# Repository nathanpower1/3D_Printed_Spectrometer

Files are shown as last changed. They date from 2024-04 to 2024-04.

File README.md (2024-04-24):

# 3D_Printed_Spectrometer
Final Report of my undergraduate Experimental Physics Career: The Development of a 3D Printed Handheld Miniature Visible Spectrometer

## Components

- **3D Printer Files**: Contains files necessary for 3D printing desgins.
- **3D Print Spectral Pics**: Spectral pictures produced through 3D printing technology.
- **MiscResultsFile**: Miscellaneous results files related to the project.
- **New Spectrometer Spectral Pics**: Spectral pictures obtained from new spectrometer design.
- **Old Spectrometer Final Data**: Final data obtained from the old spectrometer design.
- **Old Spectrometer Spectral Pics**: Spectral pictures obtained from the old spectrometer design.
- **Research Papers**: Papers used as research as part of this project.
- **Data Analysis.ipynb**: Jupyter Notebook containing data analysis scripts.
- **Physics Project Nathan Power.pptm**: Presentation slides for the project.
- **The Development of a 3D Printed Spectrometer**: Final writeup for the project. 

## Usage

1. Access the relevant folders to explore specific components of the project.
2. Utilize the 3D printer files to reproduce the spectrometer.
3. Review research papers for insights and background information on the project.

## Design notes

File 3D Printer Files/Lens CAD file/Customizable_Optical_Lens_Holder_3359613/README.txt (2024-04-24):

Customizable Optical Lens Holder by greygoo on Thingiverse: https://www.thingiverse.com/thing:3359613

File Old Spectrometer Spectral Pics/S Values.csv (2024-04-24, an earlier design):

Distance | Gray_Value
0 | 100.000
1 | 17.586
2 | 17.586
3 | 17.851
4 | 18.345
5 | 18.460
6 | 17.943
7 | 18.000
8 | 18.161
9 | 18.609
10 | 18.483
11 | 19.195
12 | 18.908
13 | 19.264
14 | 18.793
15 | 19.448
16 | 19.701
17 | 19.713
18 | 19.391
19 | 19.264
20 | 19.322
21 | 19.701
22 | 20.034
23 | 20.034
24 | 19.943
25 | 19.632
26 | 19.920
27 | 20.092
28 | 20.448
29 | 20.080
30 | 20.575
31 | 20.011
32 | 20.575
33 | 20.839
34 | 21.057
35 | 21.103
36 | 21.402
37 | 21.632
38 | 21.862
39 | 21.563
40 | 21.575
41 | 21.253
42 | 21.598
43 | 21.000
44 | 21.655
45 | 22.414
46 | 22.241
47 | 21.782
48 | 22.368
49 | 22.770
50 | 22.701
51 | 23.195
52 | 23.379
53 | 22.977
54 | 23.057
55 | 23.172
56 | 23.414
57 | 23.678
58 | 23.345
59 | 23.310
60 | 23.379
61 | 23.494
62 | 23.517
63 | 23.897
64 | 24.092
65 | 24.207
66 | 24.172
67 | 24.989
68 | 25.207
69 | 25.230
70 | 25.322
71 | 25.885
72 | 25.644
73 | 25.931
74 | 26.494
75 | 26.529
76 | 26.425
77 | 26.391
78 | 26.483
79 | 26.828
80 | 27.126
81 | 27.218
82 | 26.954
83 | 27.494
84 | 27.552
85 | 27.897
86 | 28.149
87 | 28.885
88 | 28.621
89 | 28.759
90 | 28.517
91 | 28.782
92 | 28.425
93 | 28.276
94 | 28.632
95 | 28.782
96 | 28.713
97 | 28.908
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

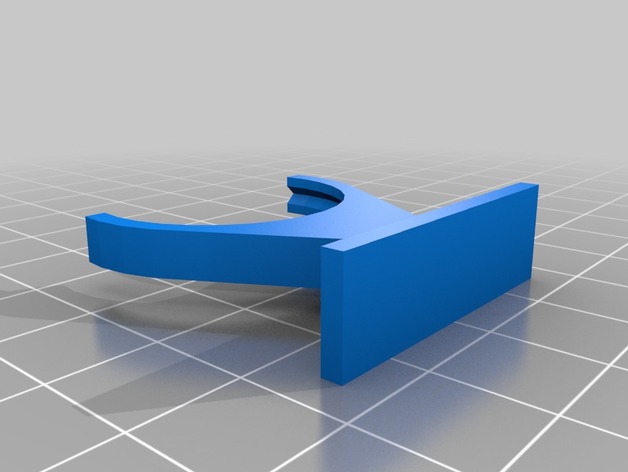
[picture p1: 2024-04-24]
3D Printer Files/Lens CAD file/Customizable_Optical_Lens_Holder_3359613/images/lense_holder_300x23.jpg

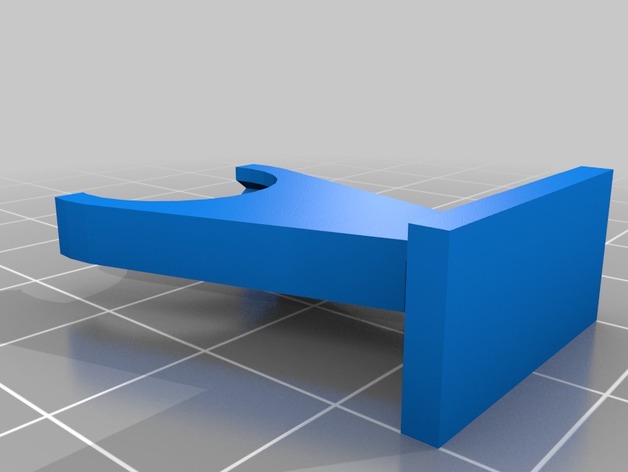
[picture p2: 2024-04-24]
3D Printer Files/Lens CAD file/Customizable_Optical_Lens_Holder_3359613/images/lense_holder_180x18.jpg

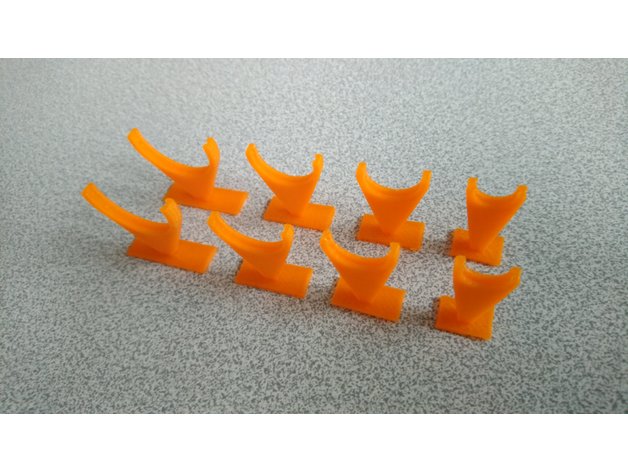
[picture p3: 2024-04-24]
3D Printer Files/Lens CAD file/Customizable_Optical_Lens_Holder_3359613/images/9351a503e8dcaec2e02d94f02c118ae2.jpg

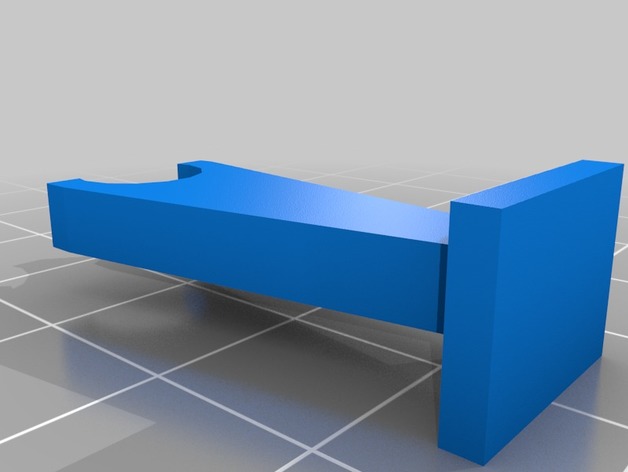
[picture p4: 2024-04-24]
3D Printer Files/Lens CAD file/Customizable_Optical_Lens_Holder_3359613/images/lense_holder_110x18.jpg

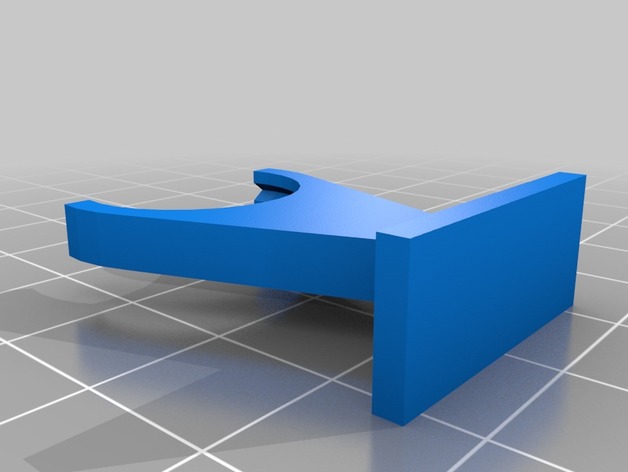
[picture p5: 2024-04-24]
3D Printer Files/Lens CAD file/Customizable_Optical_Lens_Holder_3359613/images/lense_holder_212x18.jpg

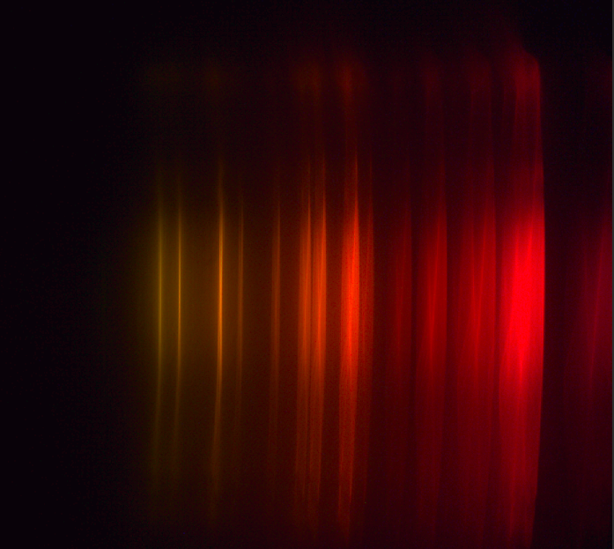
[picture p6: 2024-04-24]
New Spectrometer Spectral Pics/neon new spec 3.png

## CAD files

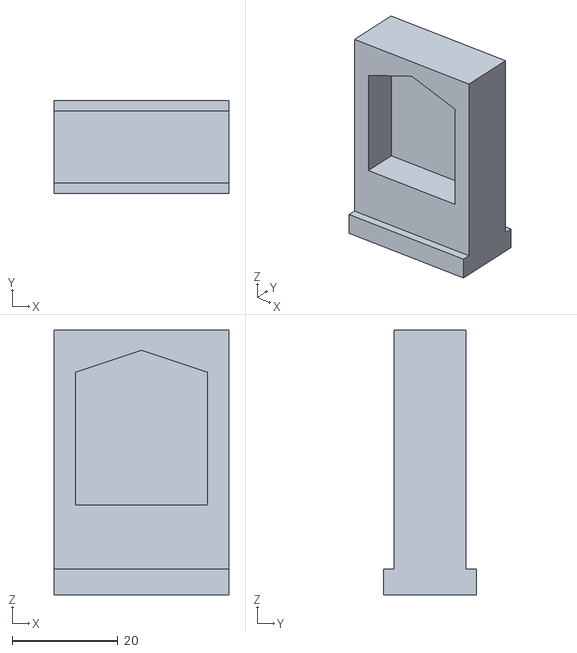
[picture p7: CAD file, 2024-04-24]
3D Printer Files/GratingFiles/New New Grating Holder v4.stl
33.0 x 17.5 x 50.0

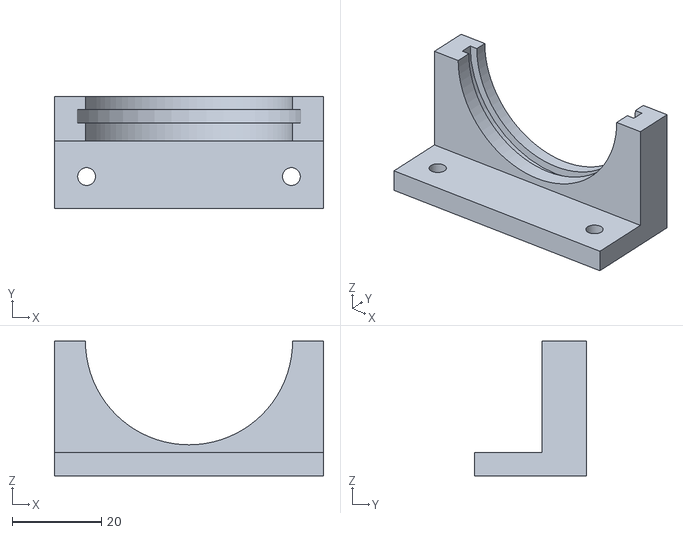
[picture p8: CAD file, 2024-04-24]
3D Printer Files/Lens CAD file/50mm-lens-holder20230105-61-r2lxff/jbeale/50mm-lens-holder/LensHolder.stl
60.4 x 25.2 x 30.2

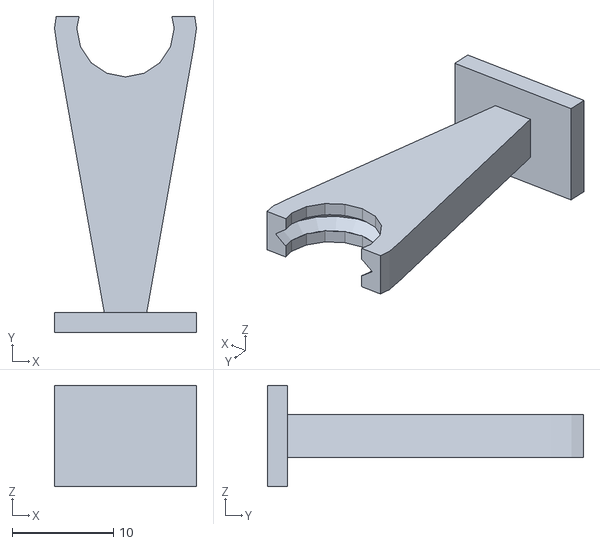
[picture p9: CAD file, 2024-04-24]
3D Printer Files/Lens CAD file/Customizable_Optical_Lens_Holder_3359613/files/lense_holder_120x18.stl
14.0 x 31.2 x 10.0

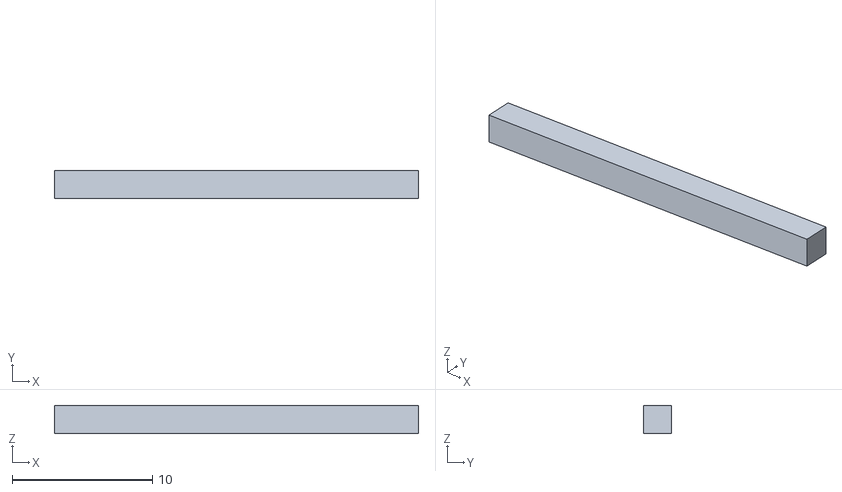
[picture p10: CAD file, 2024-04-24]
3D Printer Files/Lens CAD file/lens holder bar v1 Nathan Power.stl
26.0 x 2.00 x 2.00

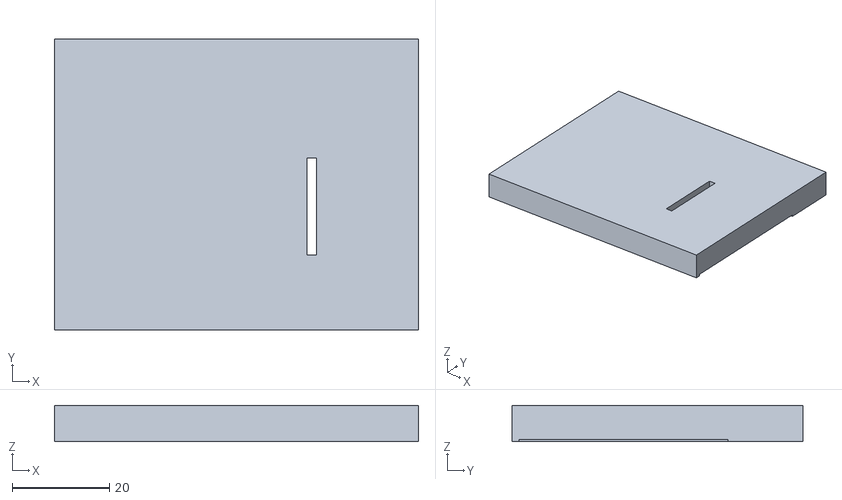
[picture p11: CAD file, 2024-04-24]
3D Printer Files/SlitFiles/Open Slit Face v2 Nathan Power.stl
75.0 x 60.0 x 7.50

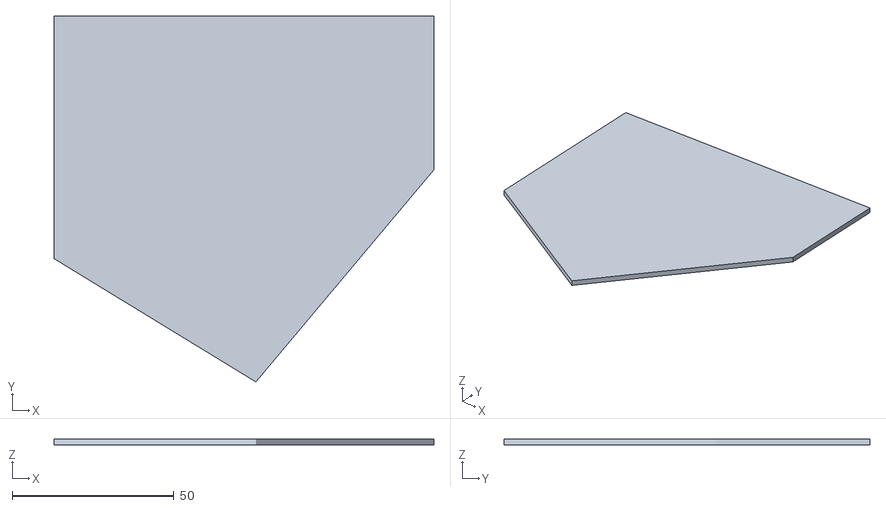
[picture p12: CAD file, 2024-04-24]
3D Printer Files/BaseFiles/Base v2.stl
117.5 x 113.1 x 2.00

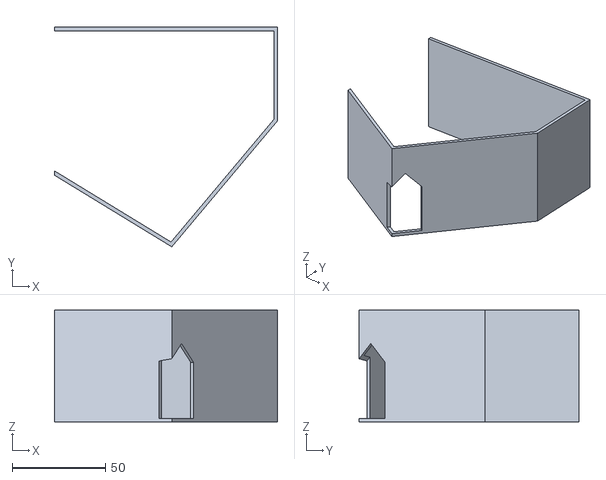
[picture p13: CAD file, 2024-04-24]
3D Printer Files/CamFiles/case 3 v5.stl
119.5 x 117.7 x 60.0

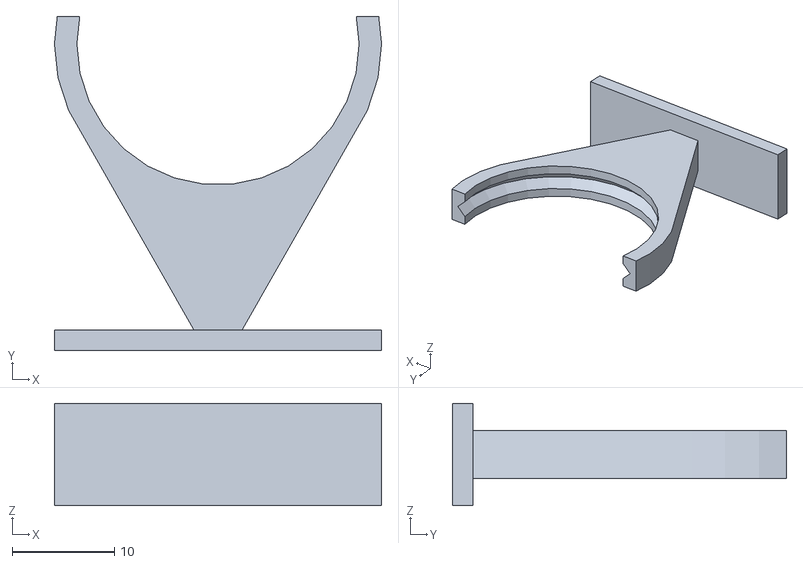
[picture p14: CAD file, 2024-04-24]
3D Printer Files/Lens CAD file/Customizable_Optical_Lens_Holder_3359613/files/lense_holder_300x23.stl
32.0 x 32.7 x 10.0

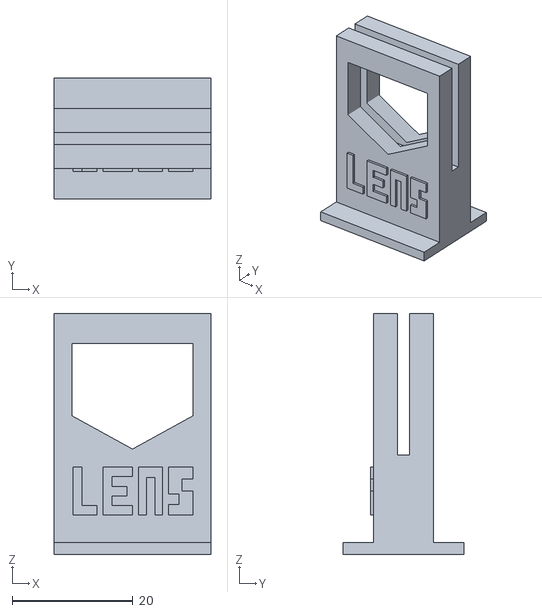
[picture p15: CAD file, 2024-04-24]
3D Printer Files/Lens CAD file/Lens Holder v3 Nathan Power.stl
26.0 x 20.0 x 40.0

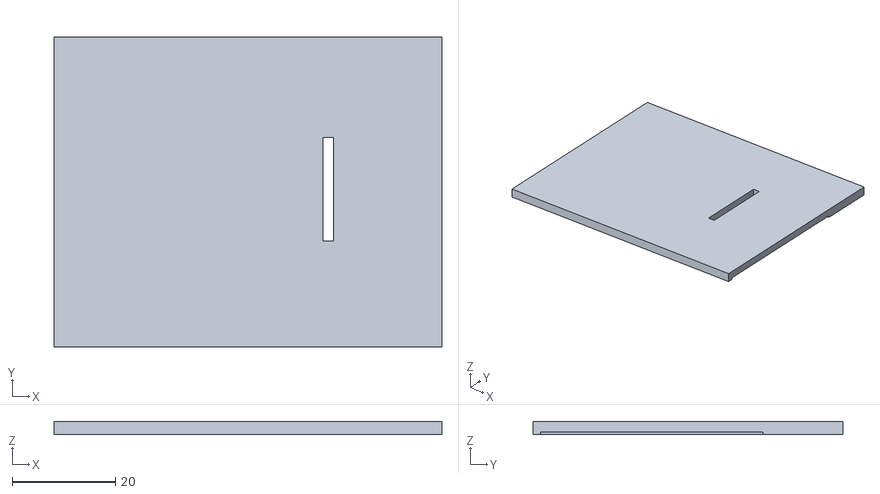
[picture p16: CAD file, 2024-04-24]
3D Printer Files/SlitFiles/Open Slit Face v4.stl
75.0 x 60.0 x 2.50

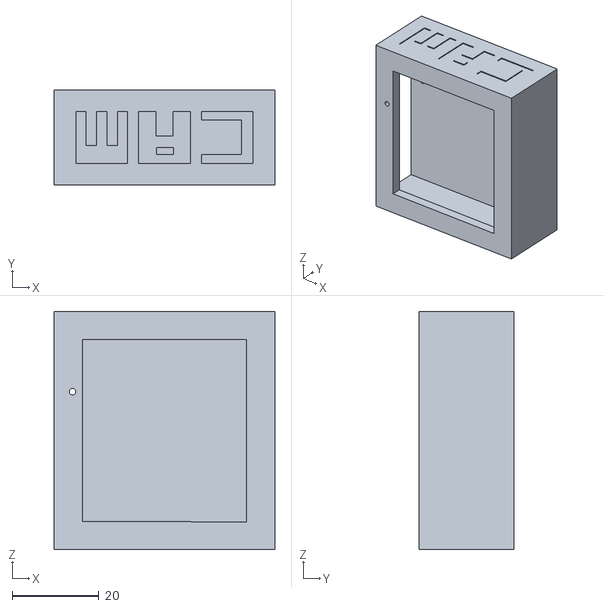
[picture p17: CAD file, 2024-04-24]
3D Printer Files/CamFiles/Camera Holder v5 Nathan Power.stl
51.0 x 22.0 x 55.0

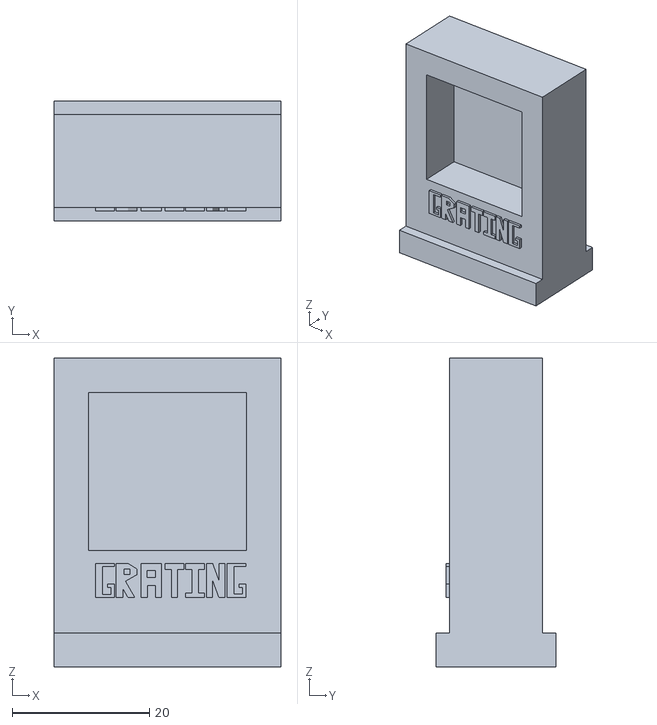
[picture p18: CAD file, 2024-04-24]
3D Printer Files/GratingFiles/Grating Holder v2 Nathan Power.stl
33.0 x 17.5 x 45.0

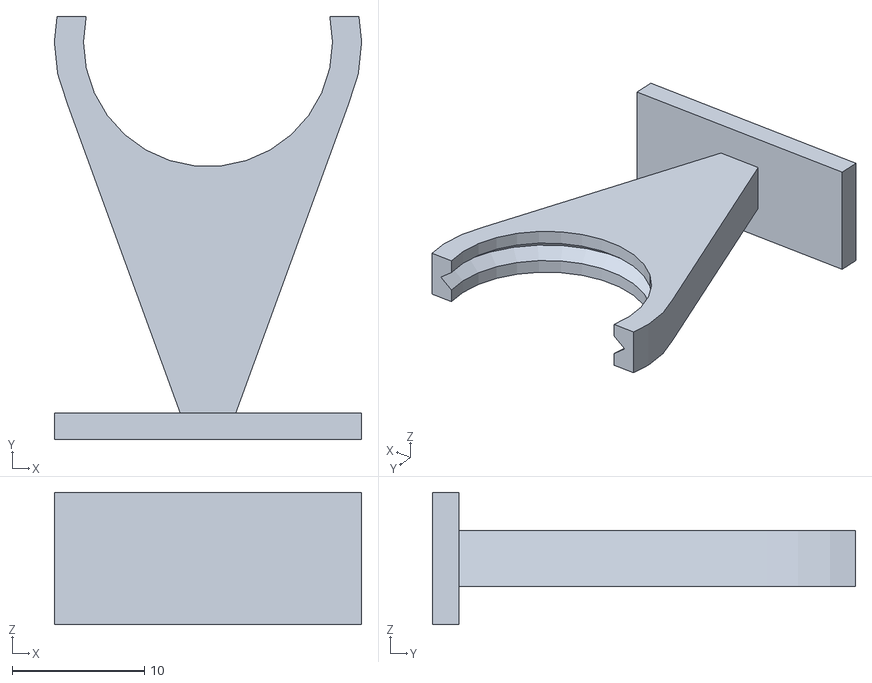
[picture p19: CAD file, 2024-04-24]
3D Printer Files/Lens CAD file/Customizable_Optical_Lens_Holder_3359613/files/lense_holder_212x18.stl
23.2 x 31.9 x 10.0

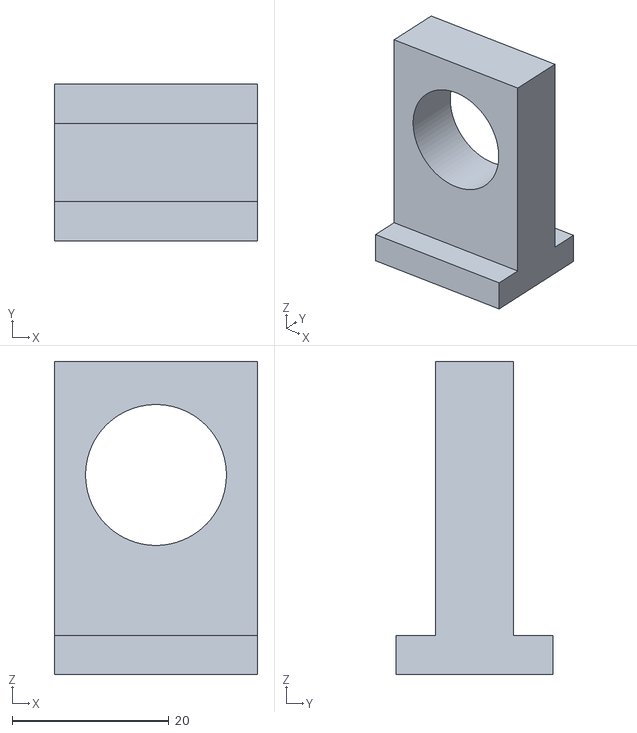
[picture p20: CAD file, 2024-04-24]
3D Printer Files/Lens CAD file/New New Lens Holder v1.stl
26.0 x 20.0 x 40.0

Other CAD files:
3D Printer Files/GratingFiles/New Grating Holder v3.stl
3D Printer Files/SlitFiles/FixedBlade.stl
3D Printer Files/CamFiles/Camera v2.stl
3D Printer Files/Lens CAD file/Customizable_Optical_Lens_Holder_3359613/files/lense_holder_110x18.stl
3D Printer Files/Lens CAD file/Customizable_Optical_Lens_Holder_3359613/files/lense_holder_customizable.scad
3D Printer Files/Lens CAD file/50mm-lens-holder20230105-61-r2lxff/jbeale/50mm-lens-holder/LensHolder.scad
3D Printer Files/BaseFiles/Base v1.f3d
3D Printer Files/BaseFiles/Base v1.stl
3D Printer Files/BaseFiles/Base v2.f3d
3D Printer Files/CamFiles/Case v1 Nathan Power.stl
3D Printer Files/CamFiles/Screw for CCD v1 Nathan Power.stl
3D Printer Files/Lens CAD file/Customizable_Optical_Lens_Holder_3359613/files/lense_holder_180x18.stl
3D Printer Files/Lens CAD file/New Lens Holder v1 Nathan Power.stl
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

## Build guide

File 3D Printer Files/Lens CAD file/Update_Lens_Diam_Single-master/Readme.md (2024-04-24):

# Update and Export variations of Lens Cap Holder for 3d printing

This is a Python script to interface with Fusion 360's API for updating the CAD model of the Lens Cap holder.
It will prompt the user to provide a minimum and a maximum lens diameter, and the width of the camera strap.
Then, the script will create versions of the lens cap holder in 1 mm increments between the minimum and the maximum diameter, for the strap width indicated by the user. It will save all the variations as STL files in a directory indicated by the user.

If you'd like to learn more about this, [I wrote an article about how the script works](https://www.makerluis.com/the-power-of-python-and-fusion-360-for-3d-printing/).

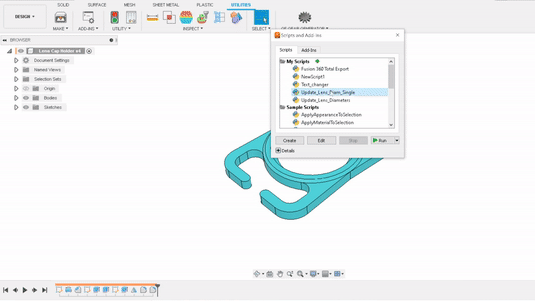
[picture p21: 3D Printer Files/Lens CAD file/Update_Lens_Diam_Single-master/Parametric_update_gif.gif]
Animated gif showing the automatic update of the model using a Python script Automatic update of the model using a Python script


#### [Download the STL files created with this parametric model](https://www.printables.com/model/129882-lens-cap-holder-for-camera-strap/comments) 
#### [Buy physical prints of the Lens Cap holder](https://vulkaza.com/collections/twothingies)

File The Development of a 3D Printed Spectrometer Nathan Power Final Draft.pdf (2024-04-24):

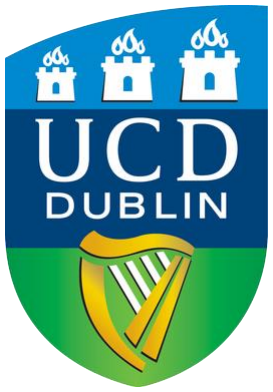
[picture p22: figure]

# The Development of a 3D-Printed Handheld Visible Spectrometer

# Nathan Power

## This project is submitted to University College Dublin in part fulfilment of the requirements for the degree:

# BSc (Hons) in Physics

### School of Physics

### Head of School: Professor Emma Sokell

### Supervisor: Assistant Professor Tom McCormack

### Submitted: April 26th, 2023

i | P a g e
i | The Development of a 3D-Printed Handheld Visible Spectrometer | Nathan Power

## Acknowledgements

I would like to thank my project supervisor, Assistant Professor Tom McCormack, for all his guidance, suggestions, and support during this project. Without his assistance, this project would not have been possible.

Collaboration with both the Electronics and Mechanics workshops in Science North was instrumental in this project, specifically, Robin O’Reilly and John Egan as they were very helpful during the 3D printing stage of this project. Thank you.

I would also like to thank Paul and Joe for their support and guidance in the labs not just during this project but also over the course of my undergraduate career.

Nathan Power

April 2023

## Abstract

This paper presents a design and implementation of a low-cost mini spectrometer that can be used for various applications in scientific research, education, and industry. The spectrometer was built using components already available in the lab and 3D printed housing and mounts, which reduced the cost significantly compared to commercially available spectrometers. The system is based on a flat diffraction grating and a CMOS sensor, and it covers the visible light spectrum from 460 to 620nm. The device is connected to a ThorLabs software for data analysis and visualization. The performance of the mini spectrometer was evaluated by measuring the spectra of different light sources and comparing them to the spectra obtained from literature. The results show that our mini spectrometer provides accurate and reliable spectral data with a resolution of approximately 2nm. The low-cost mini spectrometer presented in this paper can be a valuable tool for researchers, educators, and hobbyists who require spectral analysis but have limited budgets and/or space.

The Development of a 3D-Printed Handheld Visible Spectrometer | Nathan Power

## Table of Contents

Abstract | Error! Bookmark not defined.

The Development of a 3D-Printed Handheld Visible Spectrometer | Nathan Power

1 | P a g e
1 | The Development of a 3D-Printed Handheld Visible Spectrometer | Nathan Power
1 | Introduction

While sitting in an optics lecture in the autumn trimester of my final year, not long after I had chosen this project title as my final year physics project, the class was advised by Professor Dominic Zerulla to “Never build your own spectrometer, it is not worth the heartbreak”. With this echoing in my mind, I decided then it was time to install an AutoCad programme and get to work. I now recommend to the reader: Never build your own spectrometer unless you have a lot of patience and an optics professor to prove wrong.

1.1 Goals/Aims of this Project.
The main goal of this project was to develop a 3D printed spectrometer which is handheld, low-cost and compact in nature. This was aimed to be achieved in conjunction with maintaining a high resolution and wide operational wavelength with the intent of being able to compete with other micro-spectrometers being offered on the market today.

I believe that this is an incredibly relevant project mainly since many micro-spectrometers available on the market today are extremely expensive. From my research on low-cost non-commercially built micro-spectrometers, many fall short of the mark due to their limited spectral resolutions. This limits the amount of information that can be derived from absorption and/or emission lines. My aim is to improve on this and maintain a 1-2nm spectral resolution all in a handheld portable device.

I also believe there is an important educational application of this project. The pedagogical benefit of teaching the principles of modern spectroscopy by utilizing a simple spectrometer setup can be majorly beneficial. Optical spectroscopy is an indispensable topic in scientific education for undergraduate physics students. Using this inexpensive setup, the quantum principles of light’s interaction with matter can be explained by means of atom line emission and absorption in a classroom setting with minimal set up time. Being a final-year undergraduate experimental physics student, I believe that labs and practical experiments are just as important as the theory when it comes to fully understanding topics. Most experiments in the undergraduate physics course require highly expensive and complex instruments and equipment which highlights the importance of this low-cost project, which could be developed at home independently even, once again.

So, in this report I will introduce an optical setup that meets the criterion of high-resolution spectroscopy which remarkably remains around a factor of ten less expensive than other commercial spectrometers of similar specifications.

2 | P a g e
2 | The Development of a 3D-Printed Handheld Visible Spectrometer | Nathan Power

## 2 Spectroscopy

Our understanding of the universe comes from an expanded understanding of light as a wave across a much wider spectrum than what we can see. This in turn has led to a wave of modern technologies. Some aiming to utilize light’s wave properties to transmit information, such as audio and visual communications. While others aim to measure spectral components of physical phenomena such as mass of particles, and the chemical make-up of matter both terrestrial and extra-terrestrial.

[1]

Spectroscopy is a scientific measurement technique that investigates and quantifies the interaction of light with matter. These light-matter interactions at the molecularlevel,such as emission, absorption, fluorescence, and scattering, can be measured and analysed. These interactions are qualitatively and quantitatively analysed with light measuring instruments. The qualitative analysis is used to establish the identity of a sample while a quantitative analysis is performed to estimate the concentration of a substance. Every substance and element interact differently with light frequencies and the resulting patterns act like their own signatures or fingerprints making it possible to identify them.

[1]

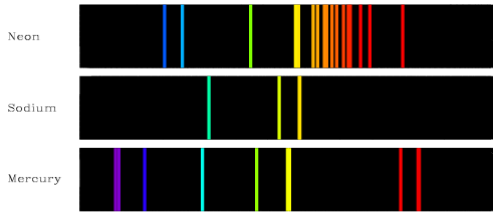
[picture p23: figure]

Fig 2.1: Emission Spectral Lines for Neon, Sodium and Mercury [2]

### 2.1 The Visible Light Spectrum

The reason that some things appear to be coloured at all to us is due to the fact that atoms and molecules absorb and emit different colours of light. So, a red shirt, for instance, appears red when sunlight shines on it because the shirt absorbs all the visible colours except the red light. Some of the red light passes through the shirt, and some is reflected from its surface. In this project, we are interested solely in the visible light spectrum.

The visible light spectrum is the segment of the electromagnetic spectrum that the human eye can view. This range of wavelengths, rather intuitively, is called visible light. Typically, the human eye can detect wavelengths from 380 to 700 nm. Cone-shaped cells in our eyes act as detectors tuned to the wavelengths in this narrow band of the spectrum. Other portions of the spectrum have wavelengths too large or too small and energetic for the biological limitations of our perception. [3] In
this report, we will explore the spectral lines of Neon, Sodium and Mercury which fall inside the visible spectrum of light.

3 | P a g e
3 | The Development of a 3D-Printed Handheld Visible Spectrometer | Nathan Power

## 3 The Spectrometer

### 3.1 What is a Spectrometer?

The spectrometer is now a common scientific instrument used to determine characteristic information about a sample by analysing its interactions with light and its spectral components. They enable us to study light’s wavelike properties to produce a spectrum and then measure the characteristics of the spectrum such as its wavelength, frequency and intensity. They can function over any range of the electromagnetic spectrum, but through their design and selection of appropriate optical components, as we will cover later, they typically operate in an application dependent region of the spectrum. [1]

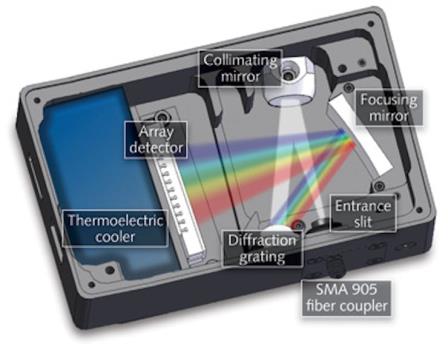
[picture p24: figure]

Fig 3.1: Typical Components of a Miniature Spectrometer [5]

### 3.2 How does a Spectrometer work?

So, what is a spectrometer and how does it work? The spectrometer as whole is a relatively simple device. The light from the sample first enters through the aptly named entrance slit and then is projected onto the collimating optic. The focal length of this optic is chosen so that it collimates the light emitted from the entrance slit and then directs the collimated beam of light onto the diffraction grating. After the light has been diffracted and separated into its chromatic components, the focusing or camera optic is used to focus the light dispersed from the grating onto the detector plane. In the case of a diffraction grating with given angular dispersion value, the focal length of the two mirrors/lenses can be designed to provide different linear dispersion values, which determines the spectral coverage for a given detector, resolution, and total length of the system. We will dive deeper into the workings of the spectrometer and its components later in this report.

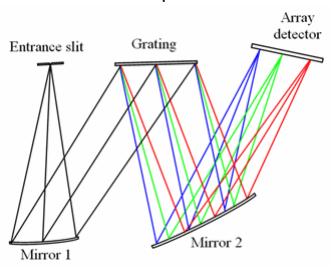
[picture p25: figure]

Fig 3.2: An Unfolded Czerny-Turner Spectrometer [1]

Perhaps the most common configuration for a spectrometer would be the Czerny-Turner configuration. A compact, flexible spectrograph design can be achieved by using the Czerny-Turner

4 | P a g e
4 | The Development of a 3D-Printed Handheld Visible Spectrometer | Nathan Power

making it an ideal setup for what we are aiming to achieve in this report. However, there are many other variations in which spectrometers can be assembled.

### 3.3 Applications of the Spectrometer

Spectrometers have a whole host of applications both in research and industrial settings. They are often used as analytical tools in R&D and manufacturing laboratories as well as in the field. Some applications include but are not limited to; determining concentrations of an element in food and beverages, identifying contaminants, checking for counterfeit or illegal substances, analysing biological compounds, performing medical analysis, and identifying structural defects.

Spectrometers can come in all shapes and sizes and with different specifications. It is possible to develop a spectrometer system which implements your smartphone within its setup. [6] Miniature spectrometers are a desirable commodity as they can be easily inserted within an experimental setup without having to sacrifice much space. The miniaturization of spectrometers has been taken to the extremes. For example, there has been a 3D-printed miniature spectrometer developed that is so small that it can fit on the tip of an endoscope or on a miniature image sensor with a footprint of 100 x 100 microns. [7]

## 4 Key Components of a Spectrometer

As previously mentioned in Section 3.2, there were five main important components to consider when building our spectrometer. These were the entrance slit, the collimating and focusing optics, the diffraction grating and the detector. The choice of these components was then bounded by the initial constraints chosen such as resolution and wavelength range which is what makes constructing spectrometers so incredibly tedious. This is why it wasso vital to have these ideal constraints and goals in mind when building our spectrometer, so it was then possible to choose the components carefully to achieve our goal.

### 4.1 The Entrance Slit

The slit is an opening that ultimately controls how much light enters the spectrometer. The width of the slit also controls the resolution. The narrower the slit is, the higher the resolution will become. However, narrower slits also decrease signal strength and throughput. These two factors are essential to balance when selecting a slit size. The angle of the light that enters the optical bench is also controlled by the slit.

Another function of the entrance slit (http://bwtek.com/spectrometer-part-1-the-slit/) is to define a clear-cut object for the spectrometer. One of the key factors that it impacts the throughput of the spectrograph is the height and width of this opening. The image width of the entrance slit is an important factor in finding the spectral resolution of the spectrometer when it is greater than the pixel width of the detector array. The image width of the entrance slit, Wi, can be estimated as: [8]

Wi = (M² × Ws

2 + W0

2
)

1
2

(1)

Where M is the magnification of the spectrometer that is set by the ratio of the focal length of the focusing optic to the collimating optic. Wo is the image broadening and Ws is the width of the entrance slit. The imaging broadening caused by the optical bench, Wo, is generally on the order of a few tens of µm for a Czerny-Turner configuration.

[8]

Therefore, reducing the width of the entrance slit below this value will not significantly improve the resolution of the system. The pixel width of the detector sets another limit on spectral resolution, as

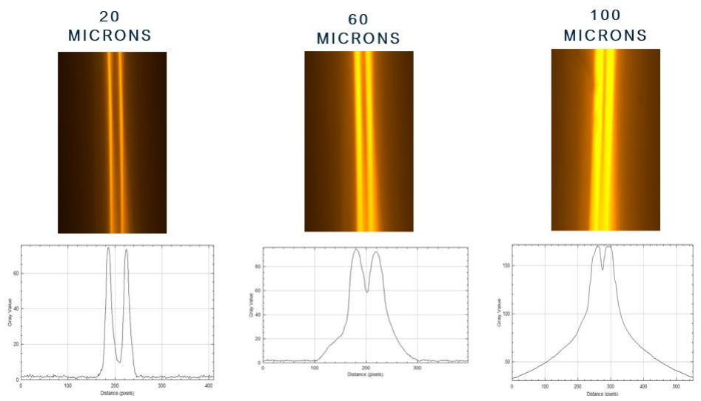
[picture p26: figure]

5 | P a g e
5 | The Development of a 3D-Printed Handheld Visible Spectrometer | Nathan Power

we will explore later in this section. Reducing the image width below the size of the pixel width will not help increase the resolution of the spectrometer.

If the resolution requirement we set in the beginning is satisfied, the slit width should be as wide as possible to enhance the throughput and signal strength of the spectrograph.

Fig.4.1: Images taken of the Sodium Doublet in the building stage of this project for different slit widths. The Sodium Doublet peaks are located at 589nm and 589.6nm respectively.

As can be seen from Fig.4.1, varying the slit width has a huge impact on the final image and profile plots taken of the spectral lines. As we see from the images, increasing the slit width has the effect of worsening the resolution and resolving power of our spectrometer. It also increases the irradiance of the image but in turn allows more background light to enter the spectrometer housing adding to the noise of the plots. It is clear to see that a large slit width would have a negative effect on our final build’s resolving power which would hinder our ability to resolve peaks such as the sodium doublet shown above.

### 4.2 The Diffraction Grating

A diffraction grating is used to separate polychromatic light into its constituent wavelengths. In the spectrometers built during this project, diffraction gratings were used to separate the wavelengths of the collected light onto different pixels of the CMOS camera for detection. The grating of a spectrometer partially determines the wavelength range and the optical resolution that the spectrometer will achieve. Choosing the correct grating was a key factor in optimizing our spectrometer for the best spectral results. Different gratings would influence our optical resolution and our maximum efficiency for our specific wavelength range. The main factor considered when choosing our grating was the groove density.

4.2.1 Groove Density
A diffraction grating (https://www.newport.com/c/diffraction-gratings_sub) is essentially a surface spanning thousands of parallel grooves. It is because of these grooves, that a grating provides the ability to separate wavelengths based on the angle that they bounce from the grating, known as dispersion. Gratings can be reflective where the

6 | P a g e
6 | The Development of a 3D-Printed Handheld Visible Spectrometer | Nathan Power

grooved surface is overcoated with a reflecting material such as aluminium [9]
, but they can also be
transmissive allowing the light to pass through them and be diffracted. The amount of dispersion is determined by the number of grooves per mm ruled into the grating. This is commonly referred to as groove density, or groove frequency.

Fig.4.2: Dispersion of light by a low and high groove density grating. [10]

This groove density is the inverse of the groove spacing. From the groove spacing we can then obtain information about the diffracted orders and incident and diffracted angles using the basic grating equation:

mλ = d(sinα + sinβ)

(2)

where m is the diffraction order, d is the groove spacing, λ is the light's wavelength, ⍺ the incident angle of light and β the diffracted angle of light leaving the grating. [11]

While setting up our spectrometer it was important to determine that we were indeed observing the first order and not the zeroth order as for the zeroth order (m = 0), α and β are equal and opposite, resulting in the light simply being reflected meaning no diffraction was taking place.

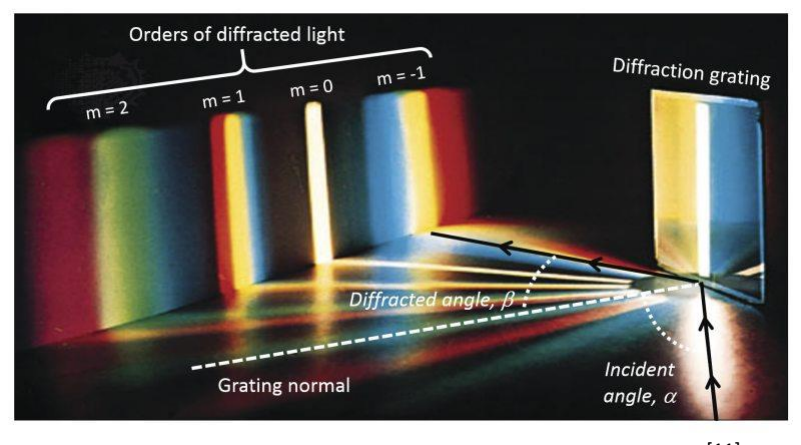
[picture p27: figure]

Fig.4.3: Polychromatic light diffracted from a grating. [11]

4.2.2 Choosing the Appropriate Groove Density As discussed above, the groove frequency of the grating helps in determining the spectrometer’s wavelength coverage and is also a major factor in the spectral resolution. The wavelength coverage of a spectrometer is inversely proportional to the dispersion of the grating due to its fixed geometry. However, the greater the dispersion, the greater the resolving power of the spectrometer. The higher groove density grating spreads the light over a larger area of the detector; increasing the spectral resolution as seen in Fig.4.2. The simple rule of thumb is when the number of grooves is doubled, the

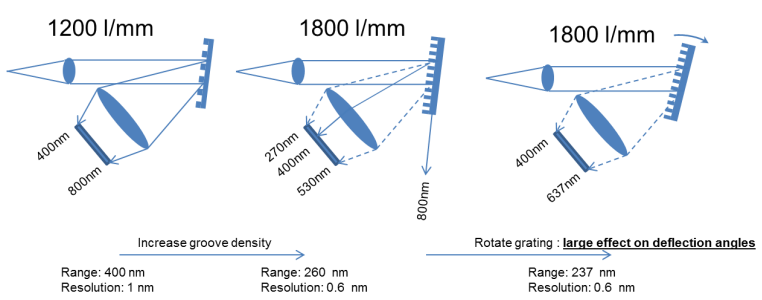
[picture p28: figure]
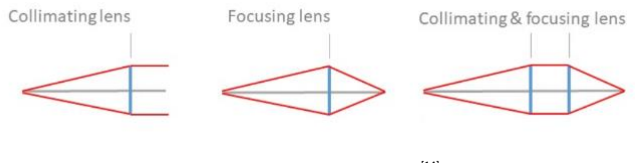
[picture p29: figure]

7 | P a g e
7 | The Development of a 3D-Printed Handheld Visible Spectrometer | Nathan Power
resolution is roughly doubled. [10] | Inversely, decreasing the groove frequency decreases the dispersion
and increases wavelength coverage at the cost of spectral resolution.

However, for any given spectrometer configuration based on reflection gratings it is furthermore possible to tune the wavelength range by rotating the grating. This is, however, not possible with spectrometers based on transmission gratings. This is due to the fact that the orders of a transmission grating do not rotate when the grating is rotated much like light going through a window. [13] Many spectrometers come equipped with the ability to rotate the grating instead of the fixed position grating implemented in our build. This way the user can span different wavelength ranges by rotating the grating in order to find and observe spectra they are interested in.

Fig.4.4: Example of reflection grating based spectrometer and the effect of changing the grating density and rotation.

[13]

Figure 4.4 illustrates how the resolution and wavelength range can be changed by changing the grating frequency and orientation. This aspect of tilting the grating was pivotal in reducing the size of our final build as it meant that we could achieve our target wavelength range while minimizing our total footprint of the spectrometer itself.

### 4.3 Collimating and Focus Optics

Collimating lenses/mirrors are optics that make the light rays, that enter the spectrometer setup, parallel. These collimating optics are placed in the setup with their focal planes aligning with the entrance slit to collimate the light. The light leaving the collimator is therefore a thin, parallel beam, which ensures that all the light from the slit strikes the diffracting element at the same angle of incidence. This is necessary as we want to form a sharp image. As one of our main goals of this project is to shrink and miniaturize our setup to handheld size, we can intuitively understand that it is in our best interest to use a collimating lens with a small focal length to reduce the size of our spectrometer.

Fig.4.5: Collimating and Focusing Lenses [14]

8 | P a g e
8 | The Development of a 3D-Printed Handheld Visible Spectrometer | Nathan Power

The role of the focusing optics in a spectrometer setup is, as the name would suggest, to focus the light reflected from the diffraction grating onto the detector. In order to get the sharpest image possible, the detector is located on the focal plane of the focusing mirror/lens. The distance between the focusing optic and the detector is termed the spectrometer focal length. The longer the spectrometer focal length the better the spectral resolution. A longer focal length provides increased spectral resolution due to wider separation of light, however, will also increase the size of the system. Fig.4.5 highlights the difference in the resolving of peaks using different focal lengths. It is of utmost importance that we selected appropriate focal lengths to achieve a handheld size while upholding the spectral resolution goals we set out to achieve.

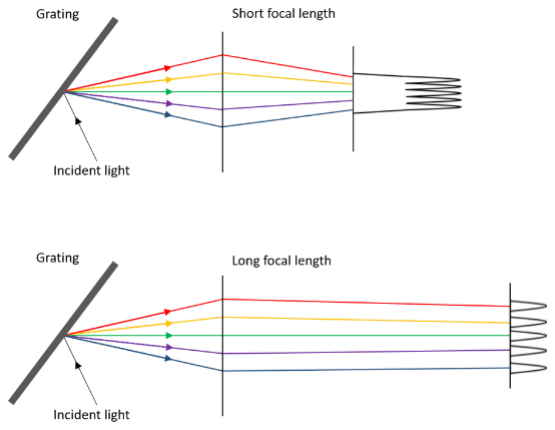
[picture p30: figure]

Fig.4.6: Dispersion of light using a short focal length (top), and a long focal length (bottom). [15]

### 4.3Detector

In modern spectrometers, linear detector and CCD arrays have enabled the development of fixed grating spectrometers. (http://bwtek.com/spectrometer-part-3a-the-detector/) When the pixels across the CCD are hit by the incident light, each pixel represents a part of the spectrum that the electronics can translate and display with a given intensity using a software programme. This development has made it possible to construct spectrometers without any moving parts, considerably reducing the size and power consumption. [16] Compact multi-element detectors have enabled the development of a new class of low-cost, compact spectrometers.

The spectral range of any spectrometer setup can be determined by the position of the grating for a given focal length and detector width. In particular, the greater the spectral dispersion is the smaller the spectral coverage falling on the active area of the detector will be. This is easy to understand since the detector has a fixed number of pixels and total width. For high spectral dispersion, each pixel will have a small range of wavelength values associated to it, and the spectral coverage will be equal to that value times the number of pixels in a single row of the detector. This can be seen in both Fig.4.2 and Fig.4.6, where for a detector with a fixed length, a higher dispersion would decrease the spectral range of our spectrometer but in turn increase the spectral resolution over this short range.

Spatial resolution is a measurement of how detailed objects are in an image based on pixels. Whereas, spectral resolution is the amount of spectral detail in a image based on the number and width of spectral lines. For a simple understanding of spatial resolution, imagine walking down a long hall towards a painting. As you get closer, your eyes start recognizing features because everything is sharper. For any type of sensor, this means the spatial resolution is becoming finer. Spatial resolution is the detail in pixels of an image. High spatial resolution means more detail and a smaller grid cell size. Whereas lower spatial resolution means less detail and larger pixel size. [17]

As we now see, the size of the pixels in the detector also has an influence on the effective resolution of a spectrograph. According to sampling theories such as Nyquist sampling of stellar

9 | P a g e
9 | The Development of a 3D-Printed Handheld Visible Spectrometer | Nathan Power

profiles[18]
, the sampling frequency should be at least greater than three times the highest frequency contained in the signal in the context of spectrographs. This means that there must be at least three pixels per spectral resolution element, as indicated by 7 (http://www.vikdhillon.staff.shef.ac.uk/teaching/phy217/instruments/phy217_inst_sampling.html) , otherwise it is the size of the detector pixels that will define the resolution of the spectrograph, not diffraction or the slit width.

To maintain focus and to not spend too much time on this section, we will not discuss the noise properties of detectors here, but such consideration is essential in computing signal, S/N ratio, and whether a particular detector is appropriate to a measurement. Therefore, when choosing the detector to use within our spectrometer build, a small pixel size with a long detector length or large pixel count are desirable commodities.

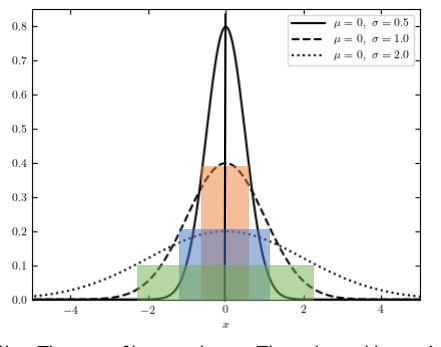
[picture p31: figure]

Fig.4.7: Sampling theory of profiles. Three profiles are shown. The coloured boxes indicate the size of the three-pixel span required to sample each profile.

## 5 Key Parameters

When designing the spectrometer builds that we will discuss in this report, it was important to have end goals and constraints in mind. First, it was important to state the measurement problem which in our case was to view spectra within the visible light range. Secondly, we must determine the desired wavelength range, dispersion, resolution and resolving power. Thirdly, determine the size we wanted the setup to be. Finally, we would then devise optical components that would meet the constraints set.

The reality is that after each step, it is likely that there will be some mismatch with constraints and goals. Perhaps resolution will be too high. Perhaps wavelength range will be too narrow. We then had to loop back to adjust some constraints in light of others. It is this dynamic back and forth among goals, parameters, and invention that makes a recipe for spectrometer design incredibly tedious. In this section, we will cover the key parameters and constraints considered when constructing our spectrometer and why they must all be compromised to maintain a low cost and compact size.

Two of the most important properties of a spectrograph are the dispersion, which sets the wavelength range of the spectrum, and the spectral resolution, which sets the size of the smallest spectral features that can be studied in the spectrum.

### 5.1 Dispersion and Wavelength Range

The primary purpose of a diffraction grating is to disperse light spatially by wavelength. A beam of polychromatic light incident on a grating will be separated into its component colours upon diffraction from the grating, with each colour diffracted along a different direction. Dispersion is a measure of the separation, either angular or spatial, between diffracted light of different wavelengths. Angular

10 | P a g e
10 | The Development of a 3D-Printed Handheld Visible Spectrometer | Nathan Power

dispersion expresses the spectral range per unit angle, and linear dispersion expresses the spectral range per unit length. [18]

Recalling the grating equation, given by Equation 2, we can obtain an expression for the angular dispersion by differentiating the grating equation with respect to wavelength, noting that α, the angle of incidence, is a constant.

[18]

D =

dβ
dλ

=

m
dcos β

(3)

As the groove frequency (the inverse of groove spacing, d) increases, the angular dispersion increases. This in essence means that the angular separation between wavelengths increases for a given order m. Thus, we can establish that the angular dispersion of a spectrum is greater for higher orders of the spectrum and smaller values of the grating spacing.

However, we use will use a linear scale to express dispersion at the detector rather than an angle. Hence, linear dispersion is defined as the rate of change of wavelength along the spectrum per unit linear distance on the detector face.

dλ
dx =

dcos β

m Ffocus

(4)

where Ffocus is the focal length of the spectrometer focusing optic.
[18]

Generally, the linear dispersion is expressed in units of nm/mm or Å/mm. For example, if a spectrometer has a linear dispersion of 10 Å/mm and the detector being used has a size of 20 mm in the dispersion direction, then the wavelength range of the resulting spectrum will be 200 Å.
[18]

### 5.2 Resolving Power

The spectral resolution or spectral resolving power, R, of a spectrometer is defined as the ability to distinguish between two wavelengths separated by a small amount, Δλ. Spectral resolution is usually quoted in terms of the dimensionless quantity: [18] [19]

R =

λ
Δλ | (5)

For example, to resolve the sodium doublet, shown in Fig.4.1, where peaks lie at 589nm and 589.6nm, the resolving power would have to be:

R =

λ
Δλ =

0.6 nm
589.6 nm

≈ 1000

Resolving power measurements are the convoluted result of all optical elements in the system, including the locations and dimensions of the entrance slit and detector, the quality of these optics, the aberrations in the images, and the magnification of the images.

### 5.3 Spectral Resolution

The terms resolving power and resolution are sometimes interchanged. While resolving power is a dimensionless quantity, resolution has spectral units, usually nanometres. One of the most important characteristics of a spectrometer is the spectral resolution. The spectral resolution of a system determines the maximum number of spectral peaks that the spectrometer can resolve. For example, if a spectrometer with a wavelength range of 200nm had a spectral resolution of 1nm, the system would be capable of resolving a maximum of 200 individual wavelength peaks across a spectrum. The level of spectral resolution required is dependent on the sample and what information the user is

11 | P a g e
11 | The Development of a 3D-Printed Handheld Visible Spectrometer | Nathan Power

aiming to obtain from the spectrum. The main factors that determine the spectral resolution achievable are, as previously discussed, slit width, diffraction grating groove density, spectrometer focal length, and detector pixel size.

After the data is collected from the sample, the spectral resolution is measured at the full width half maximum (FWHM) of the peak of interest. One very common mistake when calculating spectral resolution is to overlook the fact that in order to determine the FWHM of a peak, a minimum of three pixels is required, therefore the spectral resolution is equal to three times the pixel resolution (Δλ/pixel). [20]

### 5.4 Free Spectral Range

Free spectral range is the maximum spectral bandwidth that can be obtained in a specified order without spectral interference from adjacent orders.

[21]For any grating instrument configuration, the light of wavelength λ diffracted in the m = 1 order will coincide with the light of wavelength λ/2

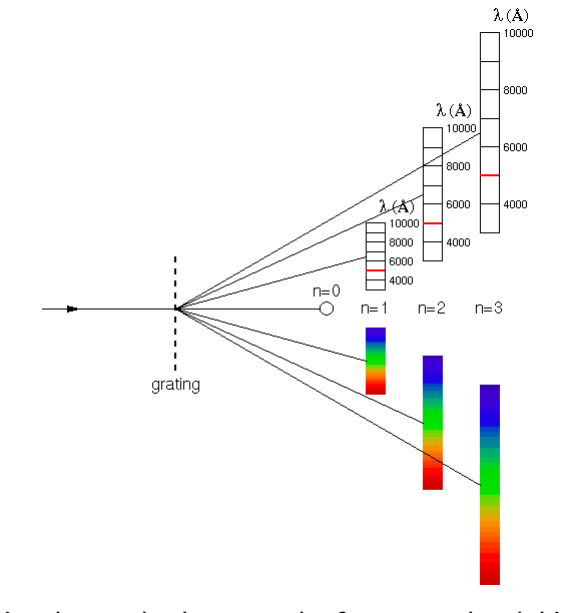
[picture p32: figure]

Fig.5.1 Schematic showing the overlap between the first, second and third spectral orders produced by a diffraction grating. [21]

diffracted in the m = 2 order, etc. In this example, the red light (600 nm) in the first spectral order will overlap the ultraviolet light (300 nm) in the second order. A detector sensitive at both wavelengths would see both simultaneously. This superposition of wavelengths, which would lead to ambiguous spectroscopic data.

[21] This will not be a problem for our builds as our detector only is sensitive to the visible spectrum. As grating spacing decreases, the free spectral range increases. It decreases with higher orders.

We can derive an expression for the free spectral range in a given order by noting that two wavelengths in adjacent orders, λ1 and λ2, that fall on top of each other must satisfy the relation; nλ1 = (n + 1)λ2. Setting λ2 as the minimum wavelength present in each, then the free spectral range, FSR, is given by: [22]

FSR = λ1 − λ2 =

λ2
n

(6)

## 6 Design Process

Now we will delve into the design process and stages which were ventured through before settling on a final design for our spectrometer. Before we started designing, we had to devise a list of parameters or constraints in which we would like our final build to reflect.

12 | P a g e
12 | The Development of a 3D-Printed Handheld Visible Spectrometer | Nathan Power
1. Wavelength Range – The Visible Range – an operational range of 50-100nm should suffice.
2. Spectral resolution – 1-2nm in order to surpass other DIY builds seen in my research.
3. Cost – less than commercially available micro-spectrometers – aim for < €500.
4. Size – aim to be a handheld and portable size - < 15cm x 15cm x 10cm.

At this stage in the build only measurement goals and environmental constraints were at focus. This way we could concentrate on what the finished product would be without being restricted by instrumental constraints.

### 6.1 Before We Build

As to make this stage as straight forward as possible, A Czerny-Turner configuration was chosen for this first design. The Czerny-Turner is the most common configuration for spectrometers due to its ability to be made compact while still maintaining the necessary resolution to perform high-level spectroscopy. In addition, only a few optical components are required: a set of confocal mirrors, a reflective diffraction grating, an entrance slit and a detector. Detection was realized by a CMOS ThorLabs camera.

6.1.1 Calibration of Components
Before we used the components within our setups, it was vital that we ensure that they are of the specification we believe them to be. Calibration was an essential step for finding the focal lengths of our mirrors and calibrating our variable slit.

To measure the focal lengths of our mirrors, we employed a simple technique. This was accomplished by focusing an image of a distant window on a screen using our mirror whose focal length was to be determined. A sharp image of the window was then formed at the focus of the concave mirror. Therefore, the distance of the screen from the mirror was equal to the focal length of the mirror.

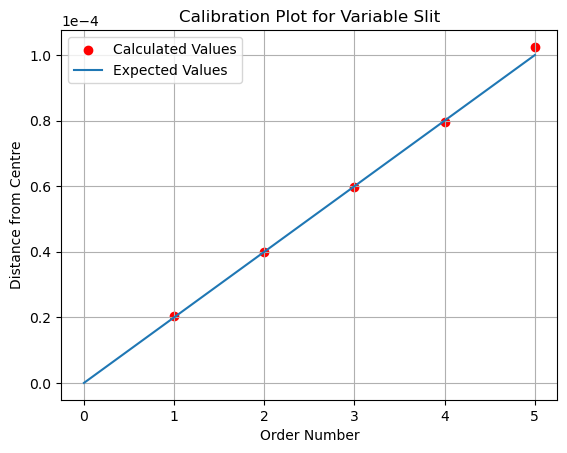
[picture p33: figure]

Fig.6.1 Calibration plot for slit width, L = 113.5cm, λ = 632nm. Expected values were values read off the slit scale and calculated values were found using Equation 8 for each order of m.

It was essential also that before any measurements were taken that the slit width of the variable slit in our setup was calibrated. We achieved this by analysing the diffraction pattern that formed when we shone a 632nm red laser through the slit at different slit widths and checking if our calculations aligned with the calculated values using the formula below:

d =

λ × L
m × z

(7)

13 | P a g e
13 | The Development of a 3D-Printed Handheld Visible Spectrometer | Nathan Power

where d is the slit width, z is distance from the centre to first minima and L is the distance from the slit to the screen. The formula above is dependent on the small angles approximation therefore L>>z.

### 6.2 Building on the Optical Bench

6.2.1 Components
Now with our components calibrated, it was time to begin constructing our first spectrometer. The plan was to first build a spectrometer on the bench with confocal concave mirrors with large focal lengths and then later aim to reduce the size of the setup to fulfil our goals. A table of the components used is listed below.
Table 6.1 Optical and electronic components used in first spectrometer build.
Component | Description
Entrance Slit | Variable Slit set to 20μm
Collimating Mirror | Concave mirror, f = 180 mm, Diameter = 50mm
Diffraction Grating | Flat Grating, 1200/mm
Focusing Mirror | Concave mirror, f = 180 mm, Diameter = 50mm
Detector | CS165CU/M - Zelux® 1.6 MP Color CMOS Camera, M6 Taps, 1440 x 1080 Pixel (1.6 MP) Sensor with 3.45 µm Square Pixels

A 1440 ×1080 pixels CMOS detector was chosen to record the spatial profile. The scale of each pixel was 3.45μm × 3.45μm, and the length of the receiving surface of the detector was 4.968mm. The grating constant was chosen as 1200 lines/mm, and the width of the slit was varied.

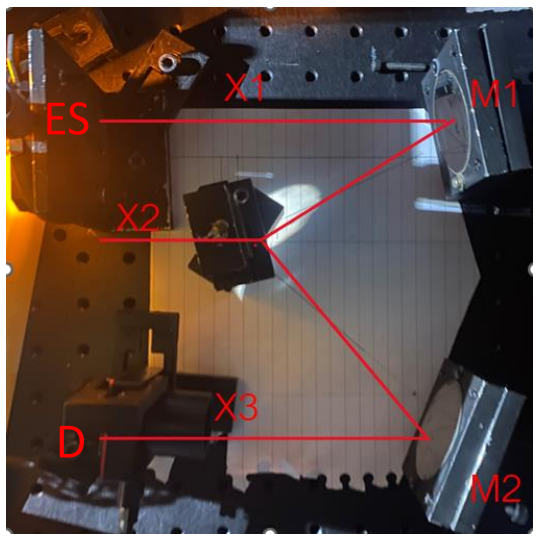
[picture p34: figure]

Fig.6.2 Setup for First Spectrometer build.

As explained in previous sections, the confocal mirrors were positioned with the collimating mirror’s focal plane aligning with the entrance slit and the focusing mirror with its focal plane falling on the detector face. Both X1 and X3 were 180mm. However, after optimization, X1 increased to 185 mm and X3 was reduced to 175 mm, other parameters like detector size and pixel width, and mirror focal length were unchanged. As we can see from Fig.6.2, the grating was indeed tilted in order to have our desired wavelength range fall on the detector as explained in Section 4.2.

14 | P a g e
14 | The Development of a 3D-Printed Handheld Visible Spectrometer | Nathan Power

In order to ensure our optical axis fell on the centre of our mirrors and passed through the centre of the slit, a 632nm red laser was used to align our components as optimally as possible. This was an important step as having our components aligned properly was vital to ensuring the best resolution was achieved.

6.2.2 Specifications
In sodium’s spectrum, there are two wavelengths of light that are quite famous, and they are jointly known as the "Sodium Doublet." When electrons fall from the 3p to the 3s orbital, they can either emit light with a wavelength of 589.0 nm or 589.6 nm. These wavelengths of light are remarkably close and provide us with a perfect opportunity to test our spectrometers resolving power.

So, by attempting to analyse and resolve the sodium doublet we could in turn determine the specifications of our build and thus adjust constraints if we fall short of our initial goals.

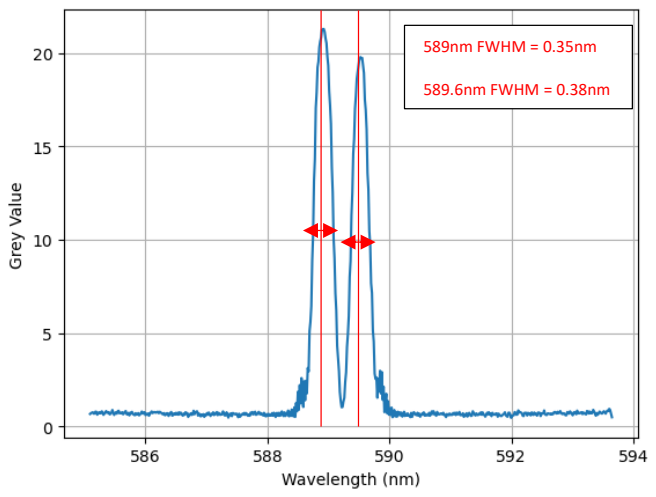
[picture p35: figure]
589nm FWHM = 0.35nm; 589.6nm FWHM = 0.38nm

Fig.6.3 Resolved Sodium Doublet using First Spectrometer setup. (Image has been cropped and does not show full wavelength range) (Slit width - 20μm)

It can be seen from Fig.6.3, the sodium doublet can be easily distinguished and is clearly resolved. Our images were obtained by connecting the spectrometer to a computer where a ThorLabs software was used to visualise and capture our spectra. The images were then processed using a software called ImageJ, where the plot profiles of the images could be analysed, and the data transferred to Python to be plotted. Resolving this doublet means our spectrometer build has a resolving power > 1000. The FWHM of the peaks can also be determined to give a value of the spectral resolution. As the grating was not in a fixed position and was able to be rotated it was possible to then observe different parts of the visible light spectrum at 13.5nm intervals.

However, as previously stated in our goals, this 13.5nm was too narrow of a range and not in line with what we aim to achieve. The estimated values for Wavelength Range and Dispersion were gathered using Equation 4 and the length of the detector. Errors on values are calculated using the approx. value of nm/pixel and each value is given by the half of the smallest possible measurement which is a half of pixel on each side of our peak in each case.

15 | P a g e
15 | The Development of a 3D-Printed Handheld Visible Spectrometer | Nathan Power

Table 6.2 Specifications for first spectrometer build.

Specification | Description
Wavelength Range | 13.5nm
Calculated Wavelength Range | 14.1nm
Resolving Power | >1000
Spectral Resolution | 0.35 ± 0.01nm @ 589nm
Dispersion | 2.70 ± 0.01nm/mm
Calculated Dispersion | 2.85nm/mm

## 7 Miniaturized Design

Our next port of call was to improve this design in line with our initial goals. The above build had an excellent resolution which surpassed our initial resolution requirement. However, it had a very narrow operational wavelength range of just 13.5nm and was too big in size. So, in our next design we aimed to address these problems and miniaturize our design and widen our spectral range.

### 7.1 Change of Optics

7.1.1 Decreased Focal Length
Therefore,to address the size and range issues of our previous design, it was clear that the focal lengths of the collimating and focusing mirror must be changed. As previously discussed, the longer the spectrometer focal length the better the spectral resolution. A longer focal length provides increased spectral resolution due to wider separation of light as highlighted in Fig.4.5. Therefore, by implementing optics of a smaller focal length we will have a smaller cone of light falling on the detector active area, increasing our operational wavelength range. This will in turn decrease our spectral resolution. But, having significantly surpassing our goals in this regard with our previous build, we can afford to loosen the reins on the 0.35 ± 0.01nm we have attained at 589nm.

7.1.2 Mirrors to Lenses
Unfortunately, as fate would have it, there was a shortage of smaller focal length mirrors available during the time of construction of this project. Due to time restrictions and other factors, we had to adapt our design in order to accommodate this. We opted to switch out our long focal length mirror for smaller focal length lenses. However, there are factors to consider when making this change such as the configuration, the light path and the changing of refractive index due to different wavelengths of light. This same phenomenon is also responsible for chromatic aberration. When white light is passed through a simple convex lens, several focal points arise in close proximity that correspond to the minor refractive index differences of the component wavelengths. This effect tends to produce coloured halos surrounding the images of objects which can be seen within our images. Correction of this aberration is usually accomplished using combinations of two or more lens elements composed of materials having different dispersive properties, such as an achromatic lens.[22]

### 7.2 Construction

7.2.1 Components
As stated above, due to the change from mirrors to lenses within our optical bench it was necessary to change our configuration. The new design can be seen below in Fig.7.1. The construction stage of

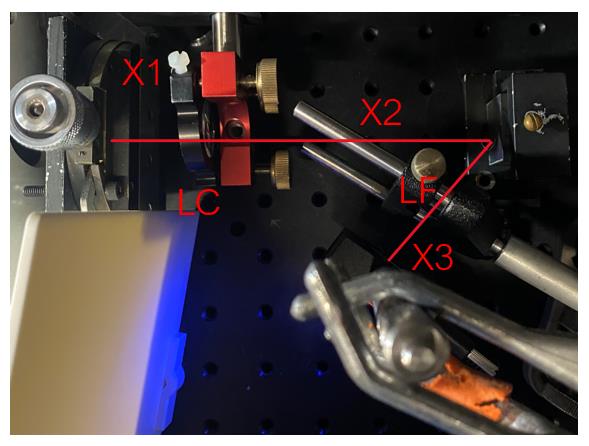
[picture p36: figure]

16 | P a g e
16 | The Development of a 3D-Printed Handheld Visible Spectrometer | Nathan Power

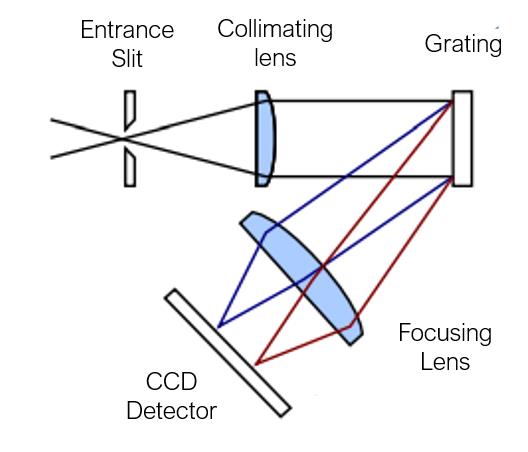
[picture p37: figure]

Fig.7.1 Closeup and Schematic of the Miniaturized Spectrometer

this version was exponentially more tedious than the last. This was due to the decreased size of the system. Therefore, the lengths between components were extremely challenging to optimize and hone in. It was also important to have the lenses perpendicular to the optical axis otherwise the light would not be refracted properly, and aberrations would occur.
Table 7.1 Optical and electronic components used in miniature spectrometer build.
Component | Description
Entrance Slit | Variable Slit set to 20μm
Collimating Mirror | Convex lens, f = 25 mm, Diameter = 18mm
Diffraction Grating | Flat Grating, 1200/mm
Focusing Mirror | Convex lens, f = 25 mm, Diameter = 18mm
Detector | CS165CU/M - Zelux® 1.6 MP Color CMOS Camera, M6 Taps, 1440 x 1080 Pixel (1.6 MP) Sensor with 3.45 µm Square Pixels

7.2.2 Specifications
As can be read in Table 7.1, the slit, diffraction grating, and detector remained unchanged. It is evident that the substitution of the optics has significantly increased the spectral range of our spectrometer. It has worsened the resolution as was to be expected. However, we remain within our initial constraints and are one step closer to our final product.
Table 7.2 Optical and electronic components used in miniature spectrometer build.
Specification | Description
Wavelength Range | 160.0nm
Calculated Wavelength Range | 159.8nm
Resolving Power | >289.5
Spectral Resolution | 0.82 ± 0.11nm/mm
Dispersion | 32.2 nm/mm
Calculated Dispersion | 32.2 nm/mm

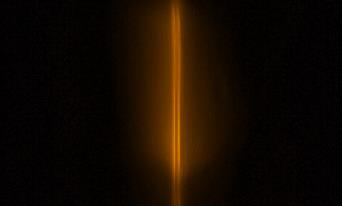
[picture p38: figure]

17 | P a g e
17 | The Development of a 3D-Printed Handheld Visible Spectrometer | Nathan Power

### 7.3 Captured Spectra

As our spectral range and spectral resolution had reached their initial goals, we could now observe the spectral emission lines of multiple sources. This way we can compare the different builds and work out if we are ready to finalise our design and fix our components in place. We have chosen Sodium, Mercury, and Neon as our three spectral lamps to observe.

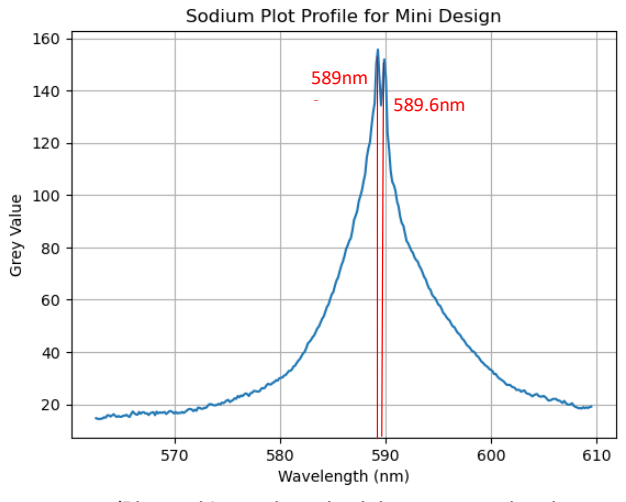
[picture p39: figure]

Fig.7.2 Sodium Doublet found using Miniature Spectrometer setup. (Plot and Image have both been cropped and do not show full spectral range)

From the images and plot profiles found using the miniature spectrometer build, we can see that our initial constraints have been followed and our goals have been achieved. We were able to produce a spectral resolution of 0.82±0.1nm which is below our 2nm limit. We were also able to maintain a wide spectral range of 160nm which can be seen in full use in the image and plot profile for Neon. The Mercury lamp was useful for resolving the doublet and finding our resolving power for our miniature build. However, unlike our initial build, our mini spectrometer was not able to resolve the notorious sodium doublet. This was expected however, and our resolving power and spectral resolution are still respectable and comply with our goals.

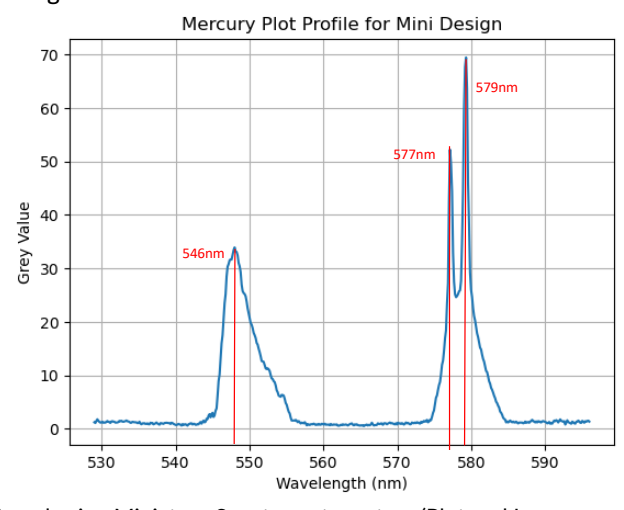
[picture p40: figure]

Fig.7.3 Mercury (a) and Neon (b) Emission Spectra found using Miniature Spectrometer setup. (Plot and Image have both been cropped and do not show full spectral range)

(a)

18 | P a g e
18 | The Development of a 3D-Printed Handheld Visible Spectrometer | Nathan Power

## 8 3D Printing

This stage in the project was pivotal as all pieces designed for the final build had to be of the correct dimensions to ensure decent throughput and alignment of our components. Any miscalculations in the design process would cause the lenses or detector to not be central on the optical axis causing a loss of focus or aberrations. The final design used the same components as the miniaturized build. All printed pieces were designed using AutoCad’s Fusion 360 and then superglued in place to ensure they would not move when the spectrometer itself was being transported.

### 8.1 Design Stage

When designing the final configuration of ourspectrometer, it was at this point that we could minimize the size of the total system. As the distance between the collimating lens and the slit, and the distance between the focusing lens and the detector were fixed, the minimization occurred in the distance between the grating and our two lenses. By minimizing this distant, we were able to fit our total system in a case of size 10cm x 9cm x 6cm.

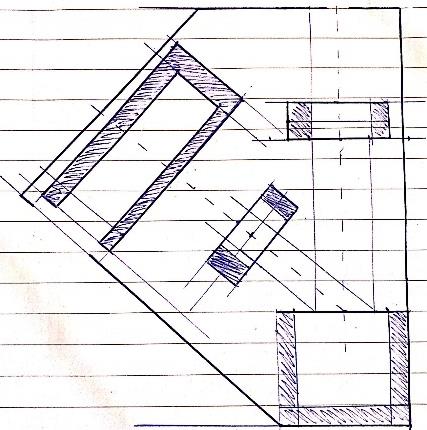
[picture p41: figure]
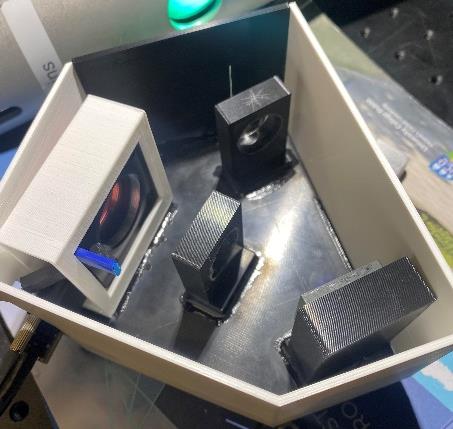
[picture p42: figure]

Fig.8.1: (a) a closeup of the slit design. (b) a view of the finished design (c) sketch of the final design

8.1.1 Designing the Slit
As variable slits are complex and often bulky systems, it was then decided that a fixed width slit would be used for our final build. The construction of this was done by designing and printing a model of an entrance slit of dimensions 2mm x 1mm (HxL). As a part of the design of this entrance slit piece, a thin slot was implemented to insert two razorblades over the larger slit. These razorblades were aligned over the centre of the slit, parallel to each other and the slit itself. A singular piece a paper was clamped

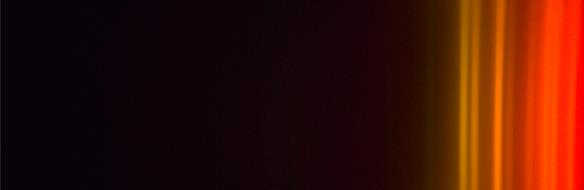
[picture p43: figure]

19 | P a g e
19 | The Development of a 3D-Printed Handheld Visible Spectrometer | Nathan Power

between them while they were glued in place and removed once the glue was dried to ensure a small enough slit was produced. Using the same process as described in Section 6.1.1 to measure the slit width which was found to be 60μm.

8.1.2 Design the Detector Mount, Grating Mount and Lens Mount.
The design process for the detector mount, grating mount and lens mount was rather straightforward. Dimensions for our components were measured using callipers and then mounts were designed and printed to their exact dimensions. A file was then used to get the mounts to fit snugly around our components which meant no adhesive was needed due to the tight fit meaning friction was our main force keeping our pieces in alignment.

## 9 Assessment of Final Build

9.1 Spectra Captured with Final Build.
When constructing the final build, it was difficult to ensure the exact perfect alignment of all components was maintained. It was not possible to adjust the alignment of the lenses on the vertical axis and the same applies to the detector. It was also not possible to adjust the alignment of our components after they had been glued down. This unfortunately led to a loss of resolution in our final build as did our increased slit width.

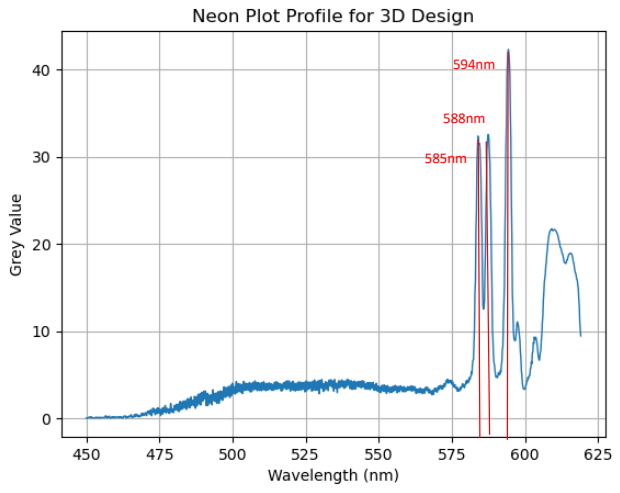
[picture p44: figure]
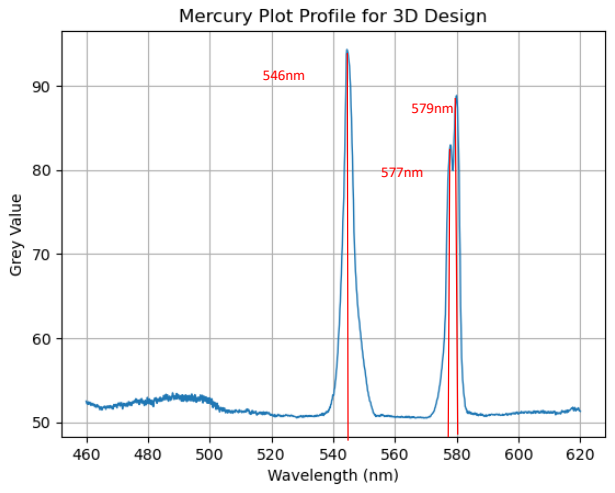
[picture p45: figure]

Fig.9.1 Mercury (a) and Neon (b) Emission Spectra found using Miniature Spectrometer setup.

20 | P a g e
20 | The Development of a 3D-Printed Handheld Visible Spectrometer | Nathan Power

As our components were all now fixed in place, our final wavelength range fell between 420nm and 620nm. This was chosen with the Mercury spectral lines in mind. We were also able to observe some of the Neon emission lines with our final build. From Fig.9.1 we can see that our resolving power did suffer and was barely able to distinguish the Mercury doublet which lie 2nm apart. This loss in resolving power can be traced back to our slit width which was fixed at 60μm rather than 20μm used in the mini-spectrometer build. However, even with this loss in resolving power, all our initial goals and constraints were achieved by our final build. A spectral resolution of 1.9nm was observed at 594nm in the Neon plot. This remains below our 2nm threshold which we held for our resolution. Our spectral range remained unaffected during construction and was measured at an impressive 160nm between 420nm and 620nm.

Table.9.1 Comparison of Miniature Build and the final 3D Build for various peaks of Neon and Mercury

Peak Position
Literature (nm) [24]

Peak Position
Measured (nm)

Build 2
(±0.11nm)

Build 3
(±0.11nm)

FWHM
(nm)

Build 2
(±0.11nm)

Build 3
(±0.11nm)
Mercury 546.0nm | 547.0nm | 546.5nm | 4.95nm | 3.3nm
Mercury 576.9nm | 577.0nm | 577.7nm | 0.94nm | -
Mercury 579.0nm | 579.1nm | 579.9nm | 0.82nm | -
Neon 585.2nm | 585.0nm | 584.1nm | - | 2.5nm
Neon 588.2nm | 588.2nm | 587.7nm | 1.4nm | 1.9nm
Neon 594.4nm | 594.5nm | 594.8nm | 1.9nm | 2.4nm

## 10 Conclusion

We can conclude that it is possible to construct a miniature low-cost spectrometer that matches the spectral resolution and sensitivity demands for atomic line emission spectroscopy using 3D printing. However, this project only opens the door for future advancements and adaptations to our design. For instance, the 60μm slit width could be drastically improved to improve resolving power and spectral resolution. Beam blocks could also be implemented within the system in to block any stray light that may incident on the detector face. Also, perhaps if the lens used were replaced with short focal length mirrors the chromatic aberration may be corrected which can be seen in our images quite clearly. This in turn would improve our build. A rotatable grating would also improve our build and allow us to span the whole visible spectrum instead of our fixed spectral range.

However, our build did in fact perform well above its price range. Our total build cost less than €500. This cost could be further improved by implementing a much cheaper detector as our detector accounted for 84% of our cost. A replacement such as the “Raspberry Pi Camera Module 3 Wide”

[25]
has smaller pixel width and a larger pixel count and active area length for $35. It also comes in a smaller size than our detector which was the driving force in determining our total build height. Alas, compared to the “Ocean Optics Stainless Steel Miniature Spectrometer”

[26], our build is a fraction of it’s €3800 price and fairs well compared to its 1.5nm resolution. The low price of our design is optimal for the application in schools, thus possibly securing hands-on experience for many students in spectroscopy.

Smaller, lower-cost spectrometers and optical benches like our build are ideal for integrating into other analytical devices. They are also perfect for performing quick and accurate measurements and can be easily transported and even used outside of a laboratory setting. This was not possible for larger, higher cost spectrometers of the past.

In conclusion, the development of a low-cost miniature 3D printed spectrometer could represent a significant advancement in the field of spectroscopy, with the potential to have a profound impact on a range of scientific and industrial and educational applications.

21 | P a g e
21 | The Development of a 3D-Printed Handheld Visible Spectrometer | Nathan Power

## Bibliograph

[1]Laser Lab Source. (Last Visited April 2023). Spectrometer Basics - Understand how Spectrometers Work and their Main Applications. Laser Lab Source. Visit at: https://www.laserlabsource.com/Spectrometers/spectrometer-basics.

[2]OpenLearn Create. (January 6th 2015). What do the colours in a rainbow tell us? Visit at: https://www.open.edu/openlearncreate/mod/page/view.php?id=53133

[3] National Aeronautics and Space Administration, 2010, Science Mission Directorate. Visible Light. Retrieved April 2023, Visit NASA Science website: http://science.nasa.gov/ems/09_visiblelight
[4] Geraerts, N. (January 2023). Visible Light Spectrum for Animals . Once Lighting. Visit at: https://www.once.lighting/en/news/the-visible-light-spectrum
[5] Chimenti, R. V. (May 1, 2013). Spectrometers; Miniature spectrometer designs open new applications potential. Laser Focus World. Visit at: https://www.laserfocusworld.com/test-measurement/spectroscopy/article/16557001/spectrometers-miniature-spectrometer-designs-open-new-applications-potential
[6] Md Arafat Hossain, John Canning, Kevin Cook, and Abbas Jamalipour, 2016,"Optical fiber smartphone spectrometer," Opt. Lett. 41, 2237-2240
[7] Andrea Toulouse, Johannes Drozella, Simon Thiele, Harald Giessen, Alois Herkommer, 2021, 3D-printed miniature spectrometer for the visible range with a 100 × 100 μm2 footprint[J]. Light: Advanced Manufacturing 2,. doi: 10.37188/lam.2021.002 (http://dx.doi.org/10.37188/lam.2021.002)
[8] B&W Tek. (2021, December 02). An Introduction to a Spectrometer - The Slit. AZoM. Retrieved on April 23, 2023 from https://www.azom.com/article.aspx?ArticleID=13374.
[9] B&W Tek. (2021, December 02). An Introduction to a Spectrometer - Diffraction Grating. AZoM. Retrieved on April 23, 2023 from https://www.azom.com/article.aspx?ArticleID=13368.
[10] Edinburgh Instruments, 2023, Grating Selection for Raman Spectroscopy, Retrieved on April 23, 2023, from https://www.edinst.com/us/technical-note-grating-selection-for-raman-spectroscopy/
[11] MKS Newport, 2023, Diffraction Grating Physics, Retrieved on April 23 2023 from https://www.newport.com/n/diffraction-grating-physics
[12] MeetOptics, 2023, Groove Density, Retrieved on April 23, 2023, from https://www.meetoptics.com/academy/groove-density
[13] Ibsen Photonics, 2023, Range and Resolution tuning in diode array spectrometers, Retrieved on April 23, 2023, from https://ibsen.com/resources/spectrometer-resources/range-and-resolution-tuning-in-diode-array-spectrometers/
[14] IDIL Fibres Optiques, 2023, Collimating or Focusing Lens System Summary, Retrieved on April 23, 2023, from https://www.idil-fibres-optiques.com/product/collimating-or-focusing-lens-system/
[15] Edinburgh Instruments, 2023, Spectral Resolution in Raman Spectroscopy, Retrieved on April 23, 2023, from https://www.edinst.com/blog/spectral-resolution-in-raman-spectroscopy/
[16] B&W Tek. (2021, December 02). An Introduction to a Spectrometer – The Detector. AZoM. Retrieved on April 23, 2023, from https://www.azom.com/article.aspx?ArticleID=13366

22 | P a g e
22 | The Development of a 3D-Printed Handheld Visible Spectrometer | Nathan Power
[17] D. Tuschel, (2020, September 01), Spectral Resolution and Dispersion in Raman Spectroscopy, Spectroscopy, Spectroscopy-09-01-20, Volume 35, Issue 9, Pages: 9–15
[18] V Dhillon, (2011 November 28), Dispersion and Spectral Resolution, University of Sheffield, Retrieved last on: April 24, 2023, from http://www.vikdhillon.staff.shef.ac.uk/teaching/phy217/instruments/phy217_inst_dispersion.html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,R%20%3D%20%CE%BB%20%2F%20%CE%94 %CE%BB.
[19] Richardson Grating Ltd, 2000, The Physics of Diffraction Gratings, Retrieved last on: April 24, 2023, from
http://astro.if.ufrgs.br/levato/instrum9/redes/chap2.htm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,P%20%3D%20.&text=P%20is%20a%20measure%20of,the%20spectrum%20(in%20mm)
[20] B&W Tek. (2021, December 02). An Introduction to a Spectrometer – Spectral Resolution. AZoM. Retrieved on April 23, 2023 from https://bwtek.com/spectrometer-part-5-spectral-resolution/.
[21] MKS Newport, 2023, Diffraction Orders, Retrieved on April 23 2023 from https://www.newport.com/n/diffraction-orders
[22] V Dhillon, (2011 November 28), Free Spectral Range, University of Sheffield, Retrieved last on: April 24, 2023, from
http://www.vikdhillon.staff.shef.ac.uk/teaching/phy217/instruments/phy217_inst_fsr.html.
[23] Michael W. Davidson, (2015 November 13), The Refraction of Light, The Florida State University, (http://www.fsu.edu/) Retrieved last on: April 24, 2023, from https://micro.magnet.fsu.edu/optics/lightandcolor/refraction.html
[24] Christian Buil, (2021), Spectral Calibration, Retrieved last on: April 25, 2023, from http://www.astrosurf.com/buil/us/spe2/hresol4.htm
[25] Raspberry Pi, (2023), Raspberry Pi Documentation, Retrieved last on: April 25, 2023, from https://www.raspberrypi.com/documentation/accessories/camera.html#hardware-specification
[26] Ocean Optics,(2007), Ocean Optics Catalog, Spectrometer Systems & Setups, , Retrieved last on: April 25, 2023, from https://www.gmp.ch/htmlarea/pdf/spektrometer.pdf
[27] Li, Z. (2013, September). On-chip optofluidic grating spectrograph for biomedical applications. In Ultrafast Imaging and Spectroscopy (Vol. 8845, pp. 78-83). SPIE.
[28] Osterheider, M., Bourdon, B., Boettcher, R., Beeken, M., & Imlau, M. (2022). A do-it-yourself Czerny–Turner spectrometer: atomic emission, absorption, reflection and fluorescence spectroscopy in natural sciences. Physics Education, 57(6), 065012.
[29] Naeem, M., Fatima, N. U. A., Hussain, M., Imran, T., & Bhatti, A. S. (2022). Design Simulation of Czerny–Turner Configuration-Based Raman Spectrometer Using Physical Optics Propagation Algorithm. Optics, 3(1), 1-7.
[30] Naeem, M., Imran, T., Hussain, M., & Bhatti, A. S. (2022). Design simulation and data analysis of an optical spectrometer. Optics, 3(3), 304-312.

23 | P a g e
23 | The Development of a 3D-Printed Handheld Visible Spectrometer | Nathan Power
[31] Shi, W., Gao, L., Zhang, L., Feng, Z., Fang, F., & Xia, G. (2022, September). The Evaluation of Spectral Resolution in the Optical Design of a Czerny-Turner Spectrometer. In Photonics (Vol. 9, No. 10, p. 678). MDPI.
[32] Nuryantini, A. Y., Mahen, E. C. S., Sawitri, A., & Nuryadin, B. W. (2017). Do it yourself: optical spectrometer for physics undergraduate instruction in nanomaterial characterization. European Journal of Physics, 38(5), 055501.
[33] Hecht, E. (2002) Optics. 4th Edition, Addison Wesley, San Francisco.

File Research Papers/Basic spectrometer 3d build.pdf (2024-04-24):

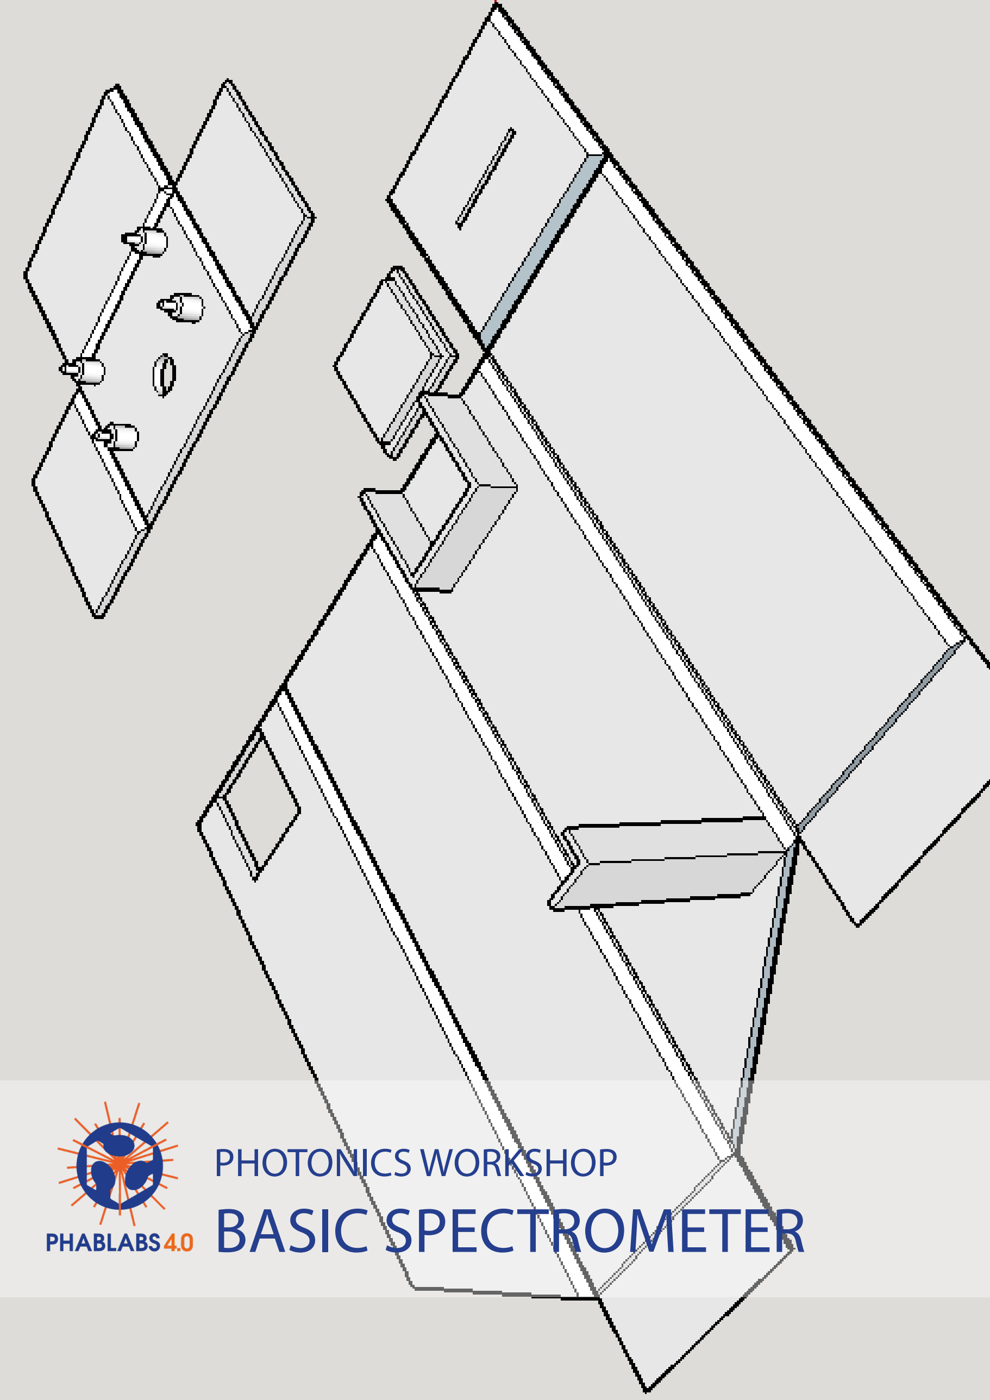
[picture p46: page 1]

# PHOTONICS WORKSHOP

# BASIC SPECTROMETER

DISCLAIMER:

By using this information you agree to be legally bound by these terms, which shall take effect immediately on your first use of the information.

PHABLABS 4.0 consortium and its member organizations give no warranty that the provided information is accurate, up-to-date or complete. You are responsible for independently verifying the information. VUB cannot be held liable for any loss or damage that may arise directly or indirectly from the use of or reliance on the information and/or products provided. PHABLABS 4.0 consortium and its member organizations disclaim all responsibility to the maximum extent possible under applicable laws:
- All express or implied warranties in relation to the information and your use of it are excluded.
- All liability, including for negligence, to you arising directly or indirectly in connection with the information or from your use of it is excluded.

This instruction is published under the Creative Commons licence CC-BY-NC.

?

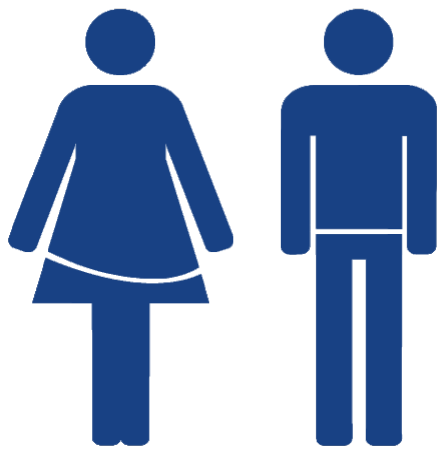
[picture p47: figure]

TARGET AUDIENCE:

Students (14-18 years old)

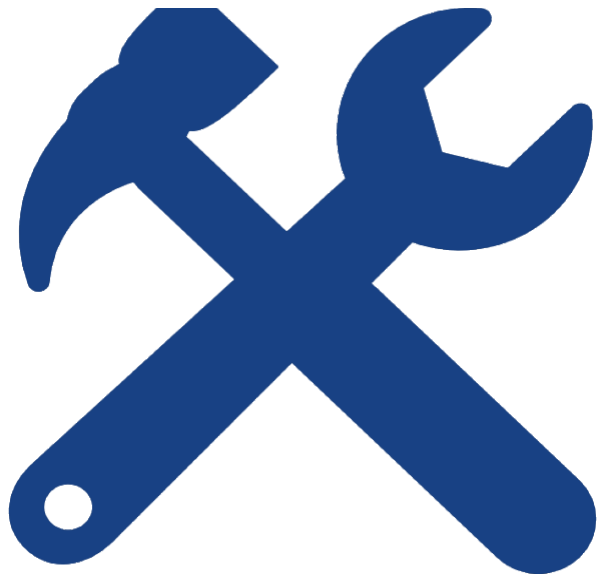
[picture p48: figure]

TOOLS:

3D printer

SUMMARY:

Spectrometry allows us to see what colours of light are present in our source, the students will create a simple spectrometer from 3D-printed material, a diffraction grating and some cellotape.

SUGGESTED TIME PLANNING: (Total: 2h)

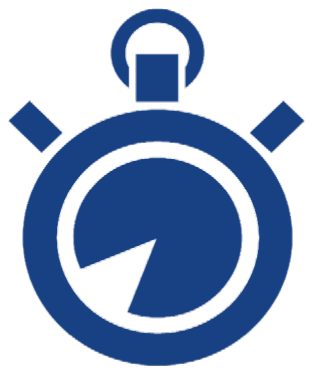
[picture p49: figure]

Timing in minutes | activity
0 - 20 | Understanding the concepts of ‘Diffraction, Interference & diffraction grating experiment’
20 - 35 | Construction of the 3-D printed spectrometer with dif-fraction grating
35 - 85 | Imaging of different light sources and calibration using images

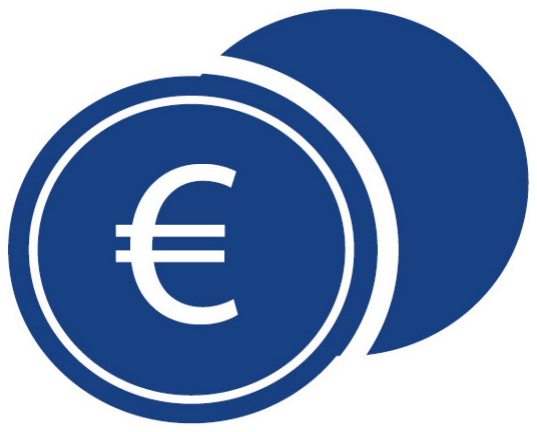
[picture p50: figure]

ESTIMATED COST:

€20

PROPERTIES OF THIS WORKSHOP

Step 1: Interference and diffraction

Interference and diffraction of waves not only produces interesting visual effects by interaction of waves in nature, they can be harnessed as a powerful tools for the study and measurement of tiny objects. Although the phenomenon has been known about for centuries, it is of special interest today. More and more technology relies on micro-‐ and nanometer-‐sized particles – too small to be seen by a normal microscope. By understanding diffraction and the interference of light waves and using them smartly, not only can we peek into this microscopic world, we can even manipulate objects in it.

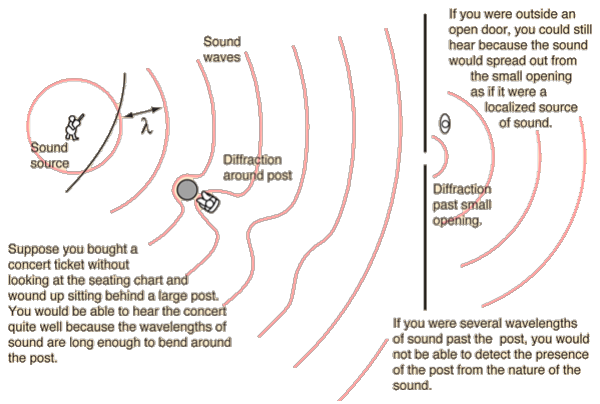
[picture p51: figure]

To gain an intuition about light diffraction, where our wavelength is in the nanoscale, we can look at our experiences with sound involve diffraction. The fact that you can hear sounds around corners and around barriers involves both diffraction and reflection of sound. Diffraction in such cases helps the sound to “bend around” the obstacles.

Light too can bend when it around corner, we have have designed a spectrometer to exploit this feature using a diffraction grating.

Step 2: Parts list

Collect all materials for each participant.

Other parts you need for doing this workshop:
-Different kinds of light sources: laserpointers, mercury lamp, sodium lamp -A3 paper
-pens
-protractors, rulers
-Computer with imageJ and java installed -Camera/smartphone

The photonics parts can be bought by EYESTvzw. (http://www.eyest.eu) The electronic parts can be bought by Fablabfactory. (http://fablabfactory.com)

### Included:

### Photonics Parts:

Diffraction grating
40 pieces

Step 3:

This workshop is based on the science of spectroscopy. The participants will construct a basic spectrometer through which they can look using their eye and then attach a smart phone to acquire images. These images will then be imported to a computer and the participants will learn how to calibrate their spectrometer and generate spectra for various light sources and transmissive media. During the workshop, the participants will perform the following tasks:

1. Design and assemble a simple diffraction experiment using a laser pointer and diffraction grating. They will learn about diffraction and the diffraction equation. They will plot the angle of diffraction for a red and green laser to illustrate the angular dependence on wavelength.
2. 3D print a miniature spectrometer through which they can look or attach to their smart phone or camera.
3. Acquire some images of various light sources and samples such as a sodium light, mercury light, LED light bulbs, daylight and examine the difference in their spectral lines.
4. Import the images to a computer and learn how to calibrate their spectrometer using open source image analysis software (ImageJ)
5. Create a macro using ImageJ to crop, average, plot graph and output spectral data.

Each participant will get to take home
1. A 3D printed spectrometer
2. Colour images of the various light sources and samples acquired using their smart phones
3. Print outs of the various spectra

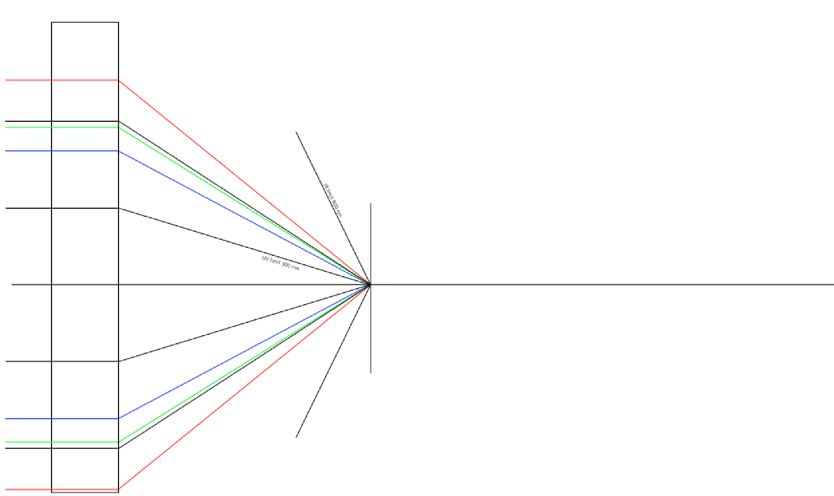
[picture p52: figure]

Diffraction experiment
Place the A3 sheet of paper on the table.

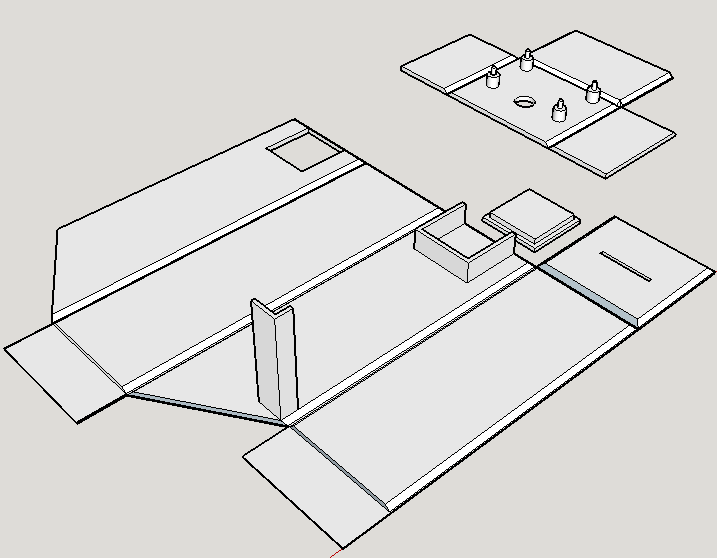
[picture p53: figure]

The laser light will be projected onto this fold.

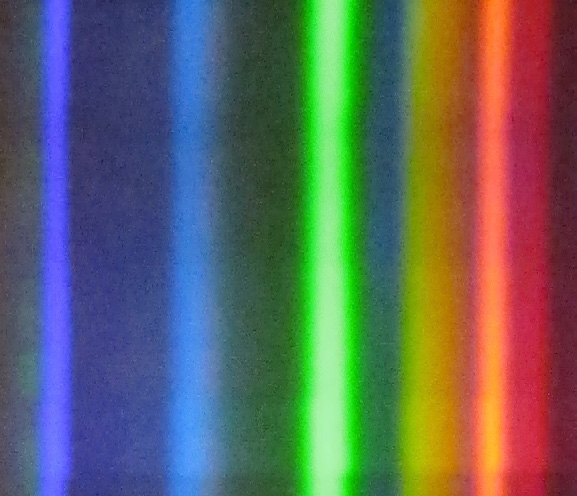
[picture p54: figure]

Draw a central axis line on the sheet of paper. The laser light will be pointed along this direction.
Place the diffraction perpendicular on the central line in the perpendicular orientation and mark its position on the central line.

First using the red laser, point it directly along the central line and through the diffraction grating.
The laser light will produce three spots on the vertical paper. The central spot is the ‘straight through’ beam from the laser. The outside spots are the diffracted beams. Using a red pen, mark the position of the three spots.
Now replace the red laser with a green / blue laser and again point the laser along the central axis and such that the central spot overlaps with the central mark from the red laser.
Mark the position of the diffracted spots using green / blue link.
Measure the distance between the diffraction grating and the projected spots. Call this distance D.
n l = d sin(theta)
Rearrange for l = l = d sin (theta) / n n is the order and you will see that only one order is seen with this diffraction grating, n = 1.
L is the wavelength of the light
D is the distance between consecutive lines of the grating = 1 / 1000 (mm)
Take down the sheet of paper and measure the distance between the central spots and the diffracted spots. For each colour measure the distance between both the left and right spots and find the average. Let this distance be y.
Calculate theta = tan-1 (y / D)

Using the above equation l = d sin (theta) / n
L = 630 nm for red.
For green, l = 560?

A good approximation for the central region of the visible part of the visible spectrum is 545 nm. Calculate the angle of diffraction for this wavelength. = 33°.
This is the reason the spectrometer is angled the way it is.

How do cameras ‘see’ the light? Will a camera sensor see outside the visible portion of the spectrum? Demonstrate using the IR light emitting diode on a remote control to show that a smart phone camera will easily see this portion of the spectrum.
Show the spectral sensitivity of silicon.
Step 4:

In addition to the diagram above, a smartphone camera positioned alongside the diffraction grating. Images of the diffraction pattern for each wavelength of light source will be taken. As the wavelength varies, spacing between the order will change. The recorded images will analysed using ImageJ software https://imagej.net/Downloads (https://imagej.net/Downloads) with the distance between dots measured in pixels. The distance between dots will also be measured using a meter stick.
Since kλ = dsin(θ), for large distance D we have θ = y / D, the students can estimate the wavelength of the light and graph the relationship between y and k, this will have a different slope for each wavelength of light source.

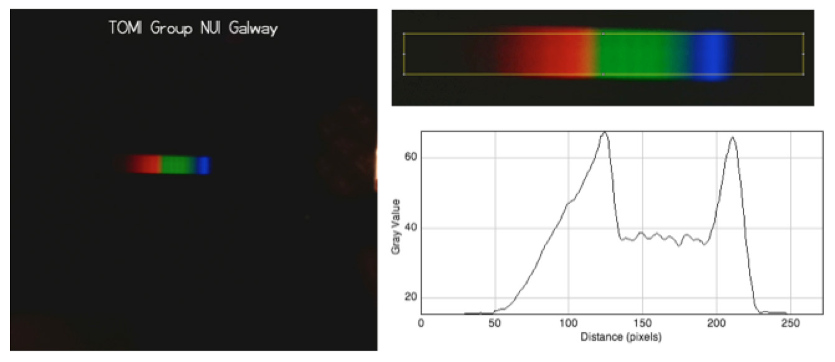
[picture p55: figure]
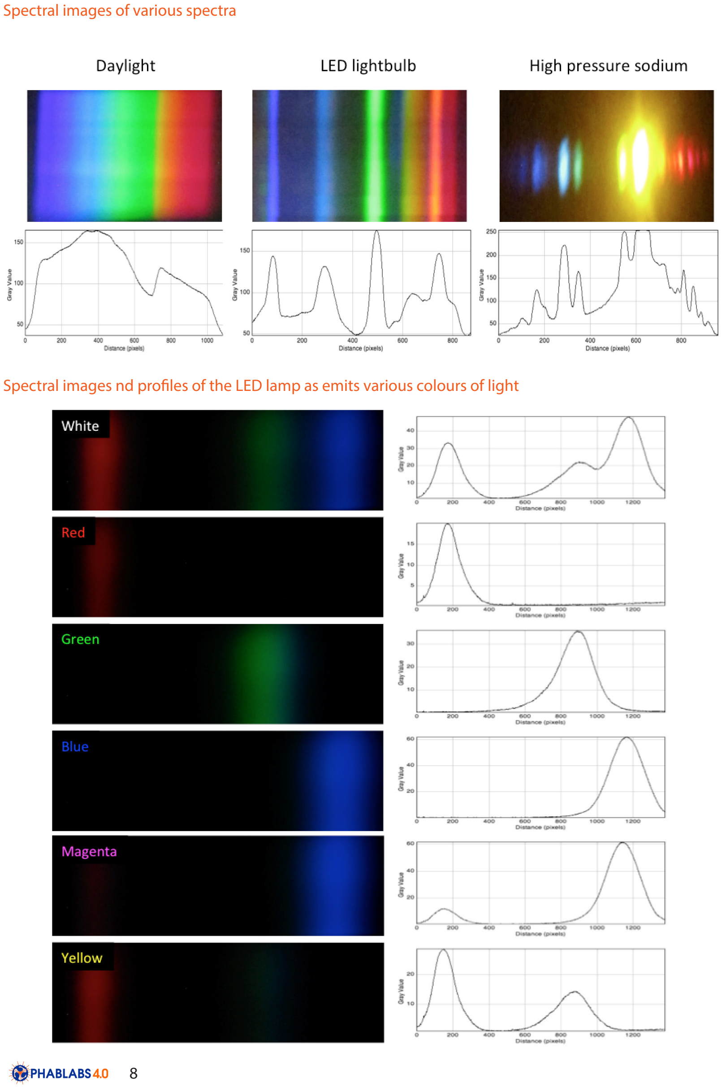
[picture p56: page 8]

Spectral images of various spectra

Spectral images nd profiles of the LED lamp as emits various colours of light

Instructions for calibrating the spectral lines

Image the spectral line emitted from low pressure sodium. This line is a known wavelength of ? = l1 Image the spectral line emitted from mercury. This line is a known wavelength of ? = l2.
The corresponding pixels are called p1 and p2.
Each pixel corresponds to (p2 – p1 / L2-l1) nm
Say 600 nm – 400 nm = 500 – 100 i.e. 200 nm across 400 pixels i.e. each pixel = 0.5 nm

Step 6: End result & conclusions

What we learned?

The participants have learned about the spectral content of different light sources and that we can measure and quantify the wavelengths of light using readily available technology. We learned about how we can use interference and diffraction to create a simple spectrometer and record data from different light sources using our eyes and our phone cameras.

Concluding thoughts

The spirit of Phablabs 4.0 is to integrate photonics with existing technologies to show that light is fascinating and can be used to gain a physical understanding of our world. By leveraging hacker tech that pervades current Fablabs and Maker projects, we can excite interest and inexplicably link the concepts of technological innovation and photonics in our participants minds.

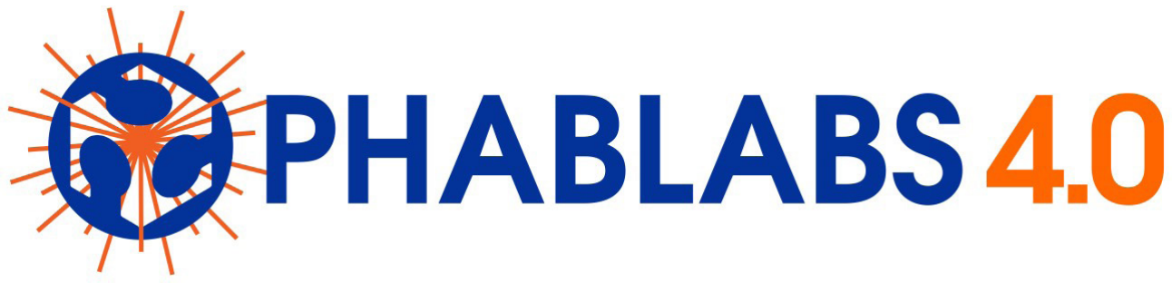
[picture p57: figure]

PHABLABS 4.0 is a European project where two major trends are combined into one powerful and ambitious innovation pathway for digitization of European industry:
On the one hand the growing awareness of photonics as an important innovation driver and a key enabling technology towards a better society, and on the other hand the exploding network of vibrant Fab Labs where next-generation practical skills-based learning using KETs is core but where photonics is currently lacking.

www.PHABLABS.eu

This workshop was set up by NUI Galway, Tissue optics & microcirculation imaging department, in close collaboration with Maker Space NUIG.

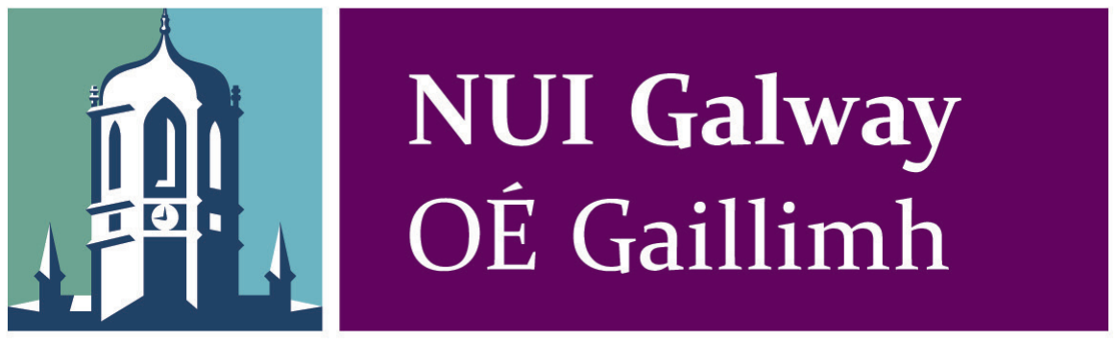
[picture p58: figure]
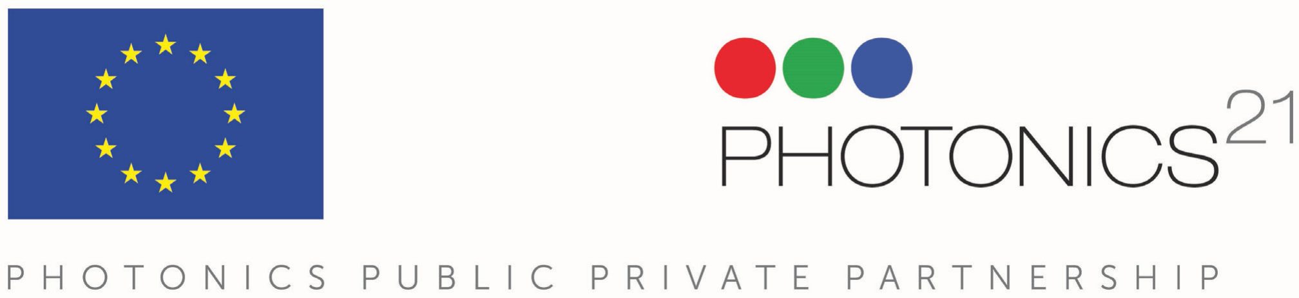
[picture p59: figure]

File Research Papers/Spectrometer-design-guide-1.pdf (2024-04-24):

# Spectrometer

# Design Guide

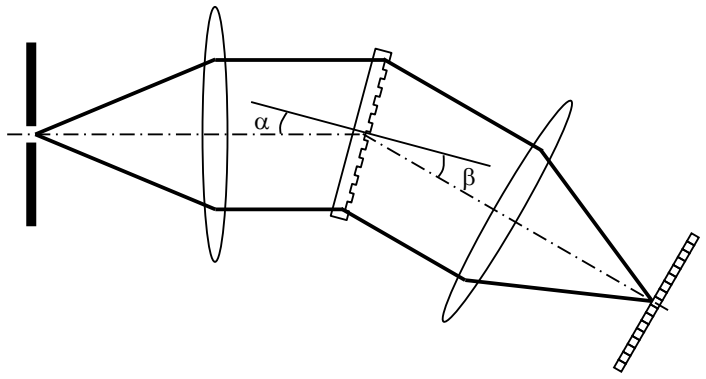
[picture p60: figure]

## Introduction

This guide provides some simple and easy to use design guidelines and formulas for designing, evaluating and comparing various diode array, diffraction grating based spectrometers designs

The input to the design process is the wavelength range you want to cover and the optical resolution by which you need to resolve the various structures in your spectrum (often peaks).

## CAUTION !

Spectometer designs made by using this guide should only be used as a starting point in your design process. If you are going to implement a spectrometer in hardware you should always use a numerical simulation tool (for instance geometrical ray tracing) to make the final design.

## How a diode array spectrometer works

Basically, a spectrometer is an optical system consisting of two lenses/mirrors that produces an image of the input slit on the detector. In between the lenses/mirrors is placed a diffraction grating which disperses different wavelengths in different angles. This causes different wavelengths of light entering the input slit to be imaged to different position on the detector array.


Input slit Collimating lens

Focusing
lens

Diffraction
grating

Detector
array

On the following pages are shown two common spectrometer geometries; the transmission grating based and the crossed Czerny-Turner. Also, the figures defines the key design parameters of a spectrometer.

Input slit; Collimating mirror; Focusing mirror; Diffraction grating; Focal length of; collimation mirror: Lc; Width of detector: LD; Groove Density: G

Minimum wavelength:
Maximum wavelength:
Wavelength range:
Resolution:
Center wavelength:

Angle of incidence:
Diffraction angle:

Grating groove density:
Focal length collimation:
Focal length focus:
Detector width:
Input slit width:

l1
l2
l2 – l1
Dl
lc = (l2 + l1

)/2

a
b
F = a + b

G
LC
LF
LD

wslit

### Input slit width: wslit

Choose a grating: G; a = sin⁻¹; 2 cos(F/2); lcG; Choose a geometry : F; LD cos(b); Choose magnification: M; cos(a); M cos(b); wslit =; Input slit; Collimating; lens; Focusing lens; Diffraction grating; Detector array; Groove Density: G; Minimum wavelength: Maximum wavelength: Wavelength range: Resolution: Center wavelength:; wslit

Input parameters:
Wavelength range: l2 – l1
Optical resolution : Dl

Input slit width: wslit

Calculate a and b as

Focal length of
collimation
lens: Lc

Choose a detector: LD

Calculate focal length of focus lens/mirror: LF

Angle of incidence:
Diffraction angle:

Calculate focal length of collimation lens/mirror: LC

Grating groove density:
Focal length collimation:
Focal length focus:
Detector width:
Input slit width:

Calculate input slit width: wslit
cos(a)

## Step 1: Choose geometry

The first step is to choose among the Czerny-Turner or LGL type geometries. For the Czerny Turner a typical value for F is around 30o wheras transmission gratings are generally used in the Littrow configuration and –1st order where a = -b => F = 0o.

## Step 2: Choose grating

The second step is to choose a diffraction grating. Most grating vendors have an on-line catalogue where you can find one or more grating options to try in your design. You should choose a grating that has high diffraction efficiency in your wavelength. The important parameter that you shall use for the design in the next steps is the groove density G.

## Step 3: Calculate diffraction angle

The angle of incidence a on the grating and the diffraction angle b for the center wavelength lc are key parameters in the spectrometer design. These angles can be calculated once the grating groove density G and the total deflection F is chosen.

## Step 4: Choose detector

The purpose of the spectrometer design is to disperse the wavelength range across the width of the detector array LD. There are a large range of diode array detectors specifically designed for spectrometers. In general, if you need a compact spectrometer you should aim for a short detector (typically 1/4” or 6.4 mm). However, if you require a broad spectral range and/or a high resolution you should aim for a wide detector (typically 1/1” or 25.8 mm).

## Step 5: Calculate focal length of focus lens

Once the width of the detector is know you can calculate the focal length of the focusing mirror/lens.

## Step 6: Choose magnification

As mentioned earlier, the spectrometer is imaging the input slit to the detector and we generally want to have the slit as wide as possible to collect as much light through the input slit as possible. Therefore, the magnification in the system M should preferably be close to 1 which means that the width of the input slit ideally is imaged 1:1 onto the detector array.

## Step 7: Calculate focal length of colli lens

As in any imaging system the magnification is determined by the ratio between the focal lengths of the two lenses in the system. For a spectrometer this ratio has to be slightly modified due to the defelction along the beam path in the grating. However, once the magnification is chosen the focal length of the collimation mirror/lens can easliy be calculated.

## Step 8: Calculate input slit width

The input slit width wslit is determined by the required optical resolution Dl and the magnification. Once you know your input slit width you are ready to evaluate if your spectromete design is viable or you have to go back and change some of your choices for grating, detector, or magnification for instance.

## Evaluation of design

Once you have done a design iteration using the 8 steps described in the previous pages you should check whether this design is practial at all. Three things that you can easily check are the input slit width, diffraction limit of optics, and diffraction limit of grating as described below.

## Is the input slit width practical?

Input slits comes in widths down to 5 microns but such narrow slits will only allow very limited amount of light to enter your spectrometer. So, if your design requires a slit of 5 – 10 microns or less you could consider the following:

- loosening your requirement for the resolution
- choosing a wider detector and choosing a grating with a higher groove density

## Diffraction limit of optics

The formulas on the previous pages does not take into account that the optics can never produce a spot smaller than the diffraction limit. You can use the following formula to calculate the FWHM in wavelength of the smallest possible spot your optics can produce:

If this value is larger than your required Dl, your system is diffraction limited by the optics and you will not be able to obtain a better resolution than Dldiffraction

## Diffraction limit of grating

The grating itself does also have a diffraction limited spot size (referred to as resolving power of the grating). The more grating lines that are being illuminated ina grating the better the resolution of the grating. The following formula gives the FWHM in wavelength of the smallest possible spot your grating can produce:

If this value is larger than your required Dl, your system is diffraction limited by the optics and you will not be able to obtain a better resolution than Dldiffraction

Dldiffraction = 1.028

lc M ( l2 – l1
)

2 LD tan(qNA)

Dldiffraction = 0.84

lc
cos(a)

2 G LC tan(qNA)

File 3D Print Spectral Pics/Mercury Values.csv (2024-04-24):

Distance_(pixels) | Gray_Value
0 | 2.5014
1 | 2.2526
2 | 2.1606
3 | 2.1728
4 | 2.4244
5 | 2.1333
6 | 2.2085
7 | 2.3822
8 | 2.2836
9 | 2.0103
10 | 2.0122
11 | 2.2648
12 | 2.1981
13 | 2.0056
14 | 2.0948
15 | 2.1737
16 | 2.0009
17 | 1.8376
18 | 2.0695
19 | 1.9878
20 | 1.7606
21 | 1.8423
22 | 2.0854
23 | 1.9033
24 | 1.8056
25 | 1.9155
26 | 1.7052
27 | 1.4770
28 | 1.6685
29 | 1.8423
30 | 1.7305
31 | 1.4573
32 | 1.5399
33 | 1.7559
34 | 1.8338
35 | 1.7296
36 | 1.9099
37 | 1.8977
38 | 1.7230
39 | 1.5315
40 | 1.8610
41 | 1.9192
42 | 1.7746
43 | 1.7587
44 | 1.9399
45 | 1.7324
46 | 1.6732
47 | 1.9746
48 | 1.9549
49 | 1.8038
50 | 1.6601
51 | 1.9127
52 | 1.8798
53 | 1.5615
54 | 1.7850
55 | 2.1023
56 | 1.8930
57 | 1.8911
58 | 2.1061
59 | 2.1023
60 | 1.8451
61 | 1.7042
62 | 2.0723
63 | 2.2582
64 | 2.0366
65 | 2.1859
66 | 2.3155
67 | 1.9155
68 | 1.9709
69 | 2.3202
70 | 2.3192
71 | 1.8516
72 | 1.5793
73 | 2.1371
74 | 2.2451
75 | 1.9249
76 | 2.1624
77 | 2.1878
78 | 1.9812
79 | 1.8845
80 | 2.2592
81 | 2.2648
82 | 1.8901
83 | 2.0066
84 | 2.4460
85 | 2.3418
86 | 2.0300
87 | 2.3700
88 | 2.3202
89 | 1.9887
90 | 1.9878
91 | 2.3596
92 | 2.4545
93 | 2.2394
94 | 2.2667
95 | 2.5540
96 | 2.5643
97 | 2.3474
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

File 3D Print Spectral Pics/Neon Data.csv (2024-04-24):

Distance_(pixels) | Gray_Value
0 | 0.0000
1 | 0.0245
2 | 0.0245
3 | 0.0301
4 | 0.0791
5 | 0.0979
6 | 0.1102
7 | 0.0612
8 | 0.0245
9 | 0.1469
10 | 0.1714
11 | 0.0490
12 | 0.0490
13 | 0.0245
14 | 0.0245
15 | 0.0000
16 | 0.0245
17 | 0.0734
18 | 0.0490
19 | 0.0612
20 | 0.1083
21 | 0.0490
22 | 0.0245
23 | 0.0979
24 | 0.0734
25 | 0.0000
26 | 0.0245
27 | 0.0979
28 | 0.0979
29 | 0.0245
30 | 0.0546
31 | 0.0791
32 | 0.0546
33 | 0.0612
34 | 0.0857
35 | 0.0734
36 | 0.0490
37 | 0.1036
38 | 0.2015
39 | 0.2815
40 | 0.1714
41 | 0.0245
42 | 0.1714
43 | 0.1469
44 | 0.0734
45 | 0.1714
46 | 0.2326
47 | 0.1224
48 | 0.0000
49 | 0.0245
50 | 0.0857
51 | 0.0612
52 | 0.1591
53 | 0.1469
54 | 0.0490
55 | 0.0734
56 | 0.1469
57 | 0.1714
58 | 0.0979
59 | 0.0490
60 | 0.0490
61 | 0.1337
62 | 0.1328
63 | 0.1704
64 | 0.1224
65 | 0.0734
66 | 0.0612
67 | 0.1591
68 | 0.1469
69 | 0.0490
70 | 0.0979
71 | 0.1469
72 | 0.0490
73 | 0.0000
74 | 0.0490
75 | 0.2119
76 | 0.1751
77 | 0.1714
78 | 0.2693
79 | 0.1224
80 | 0.0245
81 | 0.1102
82 | 0.1836
83 | 0.0734
84 | 0.0979
85 | 0.2203
86 | 0.2081
87 | 0.1158
88 | 0.1648
89 | 0.3672
90 | 0.3917
91 | 0.1714
92 | 0.0979
93 | 0.1959
94 | 0.0979
95 | 0.1224
96 | 0.3672
97 | 0.4040
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

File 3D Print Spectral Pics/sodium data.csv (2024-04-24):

Distance_(pixels) | Gray_Value
0 | 0.9591
1 | 0.3938
2 | 0.5040
3 | 0.9858
4 | 1.2738
5 | 0.8382
6 | 0.8231
7 | 1.3351
8 | 1.1742
9 | 0.5387
10 | 0.8844
11 | 0.8311
12 | 0.4462
13 | 0.5991
14 | 0.8596
15 | 0.8462
16 | 0.5804
17 | 0.6400
18 | 1.1573
19 | 0.6329
20 | 0.6880
21 | 1.1671
22 | 1.0693
23 | 0.5440
24 | 0.7982
25 | 1.1609
26 | 1.3396
27 | 0.7493
28 | 0.5600
29 | 1.1796
30 | 0.7920
31 | 0.6924
32 | 1.3440
33 | 1.1076
34 | 0.4187
35 | 0.7200
36 | 1.1120
37 | 1.2533
38 | 0.6951
39 | 0.7200
40 | 1.3360
41 | 0.8053
42 | 0.7724
43 | 1.5022
44 | 1.4756
45 | 0.6631
46 | 0.7396
47 | 1.1609
48 | 1.1876
49 | 0.7582
50 | 1.5351
51 | 1.4693
52 | 0.6969
53 | 0.5253
54 | 1.2569
55 | 1.3964
56 | 0.6853
57 | 0.5929
58 | 1.4187
59 | 1.7164
60 | 0.9209
61 | 1.7209
62 | 1.5369
63 | 0.7804
64 | 0.7289
65 | 1.3147
66 | 1.2658
67 | 0.6489
68 | 0.7796
69 | 0.9813
70 | 1.2738
71 | 1.1582
72 | 1.5360
73 | 1.0960
74 | 0.6622
75 | 0.7324
76 | 1.0764
77 | 1.1262
78 | 0.8524
79 | 0.6400
80 | 1.2293
81 | 0.7573
82 | 0.8160
83 | 1.3076
84 | 1.2720
85 | 0.6622
86 | 0.4187
87 | 0.9920
88 | 1.3173
89 | 0.7822
90 | 0.6391
91 | 1.2356
92 | 0.8453
93 | 0.8756
94 | 1.4053
95 | 1.3520
96 | 0.8018
97 | 0.6924
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
